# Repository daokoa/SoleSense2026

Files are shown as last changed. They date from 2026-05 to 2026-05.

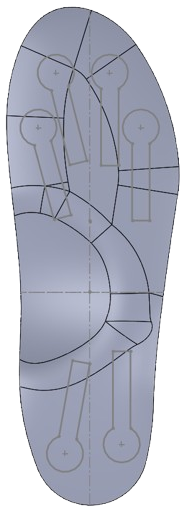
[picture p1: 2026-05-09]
software/frontend/solesense-v2/solesense.png

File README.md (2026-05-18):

# SoleSense







A 3D-printed smart running insole that runs a full gait analysis offline -- cadence, ground contact time, impact rate, pronation, foot-pressure heatmap, and research-backed injury flags -- and serves it over the device's own WiFi access point. No app, no cloud, no internet.

*UCI · Spring 2026*

---

## Quickstart

1. **Power on** the insole.
2. **Connect** your phone to WiFi `SoleSense` (password `solesense`).
3. **Open** `http://192.168.4.1/` (or `http://solesense.local/` on iOS / macOS).
4. **Sign in**, tap **Start Run**, run, tap **Stop**, read the report.

---

## Features

**Firmware** -- ESP32-C3 at 500 Hz
- Six-FSR matrix scan plus MPU-6050 IMU. All analysis runs on-device.
- Incremental Goertzel FFT, top-N outlier buffer, Welford running stats -- no raw samples are stored.
- Multi-slot crash-recoverable run snapshots in flash; runs survive WiFi blips and phone disconnects.
- NVS-backed user accounts with SHA-256 + per-user salt PIN hashing. One in-RAM session at a time.

**Frontend** -- single self-contained HTML file
- Sign-in and device-claim flow, live timer, anatomical foot diagram with real-time FSR fill.
- Report screen with verdict card, foot-pressure heatmap, findings cards, and an optional AI Coach. The Coach is proxied through a Cloudflare Worker that holds the OpenAI key -- the device never touches it.

**Injury flags** -- research-backed thresholds (full citations in [`docs/research.md`](docs/research.md))
- Heel striking · high impact rate · low cadence · overpronation · supination · medial/lateral asymmetry · FSR saturation diagnostic

---

## How it works

The MCU samples 6 FSRs and 6 IMU axes at 500 Hz and runs the full analysis on-device. FFT magnitudes, Welford stats, and the outlier buffer flush every 3 s to a 10-slot ring buffer in flash. The phone is a thin renderer: it polls `/api/run-state` for the timer and `/api/run-report` for the metrics. Disconnects pause the run cleanly; reconnects resume from the latest valid flash slot.

Full architecture rationale: [`docs/design/specs/2026-05-06-v0.2-data-architecture.md`](docs/design/specs/2026-05-06-v0.2-data-architecture.md).

---

## Hardware

| Component | Role | Status |
|---|---|---|
| Seeed XIAO ESP32-C3 | MCU, WiFi AP, HTTP server | flashed, running |
| MPU-6050 | 6-axis accel + gyro (I²C @ `0x68`) | wired, reads validated |
| FSR 402 × 6 | Pressure sensors (3-zone × medial/lateral) | wiring in progress |
| 1N5819 Schottky × 6 | One per FSR -- prevent voltage leakage between sensors during matrix scan | wired in WD4 |
| LIR2450 × 3 (parallel) | 3.7 V Li-ion coin cells, ~360 mAh | pending |
| TPU 85A | 3D-printed insole shell | pending |

---

## Pin map

Per [`hardware/electricalpins.pdf`](hardware/electricalpins.pdf); pin constants in [`firmware/SoleSenseV2/config.h`](firmware/SoleSenseV2/config.h).

| XIAO pin | GPIO | Use |
|---|---|---|
| D0 / A0 | 2 | ADC A — shared by FSR 1A & 2A |
| D1 / A1 | 3 | ADC B — shared by FSR 1B & 2B |
| D2 / A2 | 4 | ADC C — shared by FSR 1C & 2C |
| D4 | 6 | I²C SDA → MPU-6050 |
| D5 | 7 | I²C SCL → MPU-6050 |
| D6 | 21 | MPU-6050 INT (reserved) |
| D7 | 20 | FSR Set 1 power (FSRs 1A, 1B, 1C) |
| D8 | 8 | FSR Set 2 power (FSRs 2A, 2B, 2C) |
| D9 | 9 | Wake button (on-board BOOT) |

### FSR wiring

**Three pull-down resistors total**, one per ADC pin -- *not* one per FSR. Each pull-down forms the bottom half of a voltage divider with whichever of the two FSRs on that ADC is currently powered.

```
D7 ──[FSR 1A]──┐
                ├── D0 ──[10 kΩ]── GND
D8 ──[FSR 2A]──┘
```

The firmware time-multiplexes which set is active. Only one FSR is ever in the divider at a time; the inactive set's power pin is driven LOW, so any ghost-current path through the unpowered FSR shorts to ground rather than perturbing the active read.

### FSR → zone mapping (Choi 2024, +E-at-heel)

| Channel | FSR | Zone |
|---|---|---|
| ch0 | 1A | Heel medial |
| ch1 | 1B | Heel lateral |
| ch2 | 1C | Midfoot medial |
| ch3 | 2A | Midfoot lateral |
| ch4 | 2B | Forefoot medial |
| ch5 | 2C | Forefoot lateral |

---

## API

| Method | Path | Auth | Purpose |
|---|---|---|---|
| `GET`  | `/` | public  | Serves the SPA from LittleFS |
| `GET`  | `/api/device` | public  | Firmware version, board, sample rate, free heap, fs bytes |
| `GET`  | `/api/sensor` | public  | Live FSR + IMU snapshot (`fsr[]`, `fsrEma[]`, `ax/ay/az`, `gx/gy/gz`) |
| `GET`  | `/api/run-state` | public  | `recording, run_active, elapsed_ms, sample_count, clients_connected, outlier_count` |
| `GET`  | `/api/run-report` | public  | Final metrics: steps, cadence, contactMs, loadingRate, pronate, medialPct, lateralPct, zoneAvg, imuConnected, imuImpacts, flags |
| `GET`  | `/api/run-spectrum` | public  | FFT magnitude (12 channels × 18 bins, Goertzel) |
| `GET`  | `/api/run-outliers` | public  | Top-N outliers (`ts, channel, value, sigma`) |
| `GET`  | `/api/storage-state` | public  | Slot count + per-slot byte usage |
| `POST` | `/api/storage-selftest`  | public  | On-bench validation of the ring buffer |
| `POST` | `/api/fft-selftest` | public  | 1.95 Hz sine validation -- expect ~100 mag on the on-bin frequency |
| `GET`  | `/api/auth/state` | public  | `ownerExists, sessionActive, username, userCount, maxUsers` |
| `POST` | `/api/auth/register` | public, capped (`MAX_USERS=50`, 3-per-60-s) | Walk-up signup; first call claims the device |
| `POST` | `/api/auth/login` | rate-limited | `username, pin → token, body_kg` |
| `POST` | `/api/auth/logout` | session | Clear active session |
| `GET`  | `/api/auth/profile` | session | Current user info |
| `POST` | `/api/auth/profile` | session | Update body_kg / height_cm for the current user |
| `POST` | `/api/start` | session | Begin recording |
| `POST` | `/api/stop` | session | End recording, flush state |
| `POST` | `/api/data/clear` | session | Wipe all `/run_slot_*.bin` files (resets Last Report) |
| `POST` | `/api/calibrate/zero` | session | Zero the 6 FSRs (insole unloaded) |
| `POST` | `/api/calibrate/imu` | session | Zero accel + gyro (insole flat) |
| `POST` | `/api/sleep` | session | Enter deep sleep; wake on GPIO9 LOW |

Protected endpoints require `Authorization: Bearer <token>`. Handler-by-handler detail in [`firmware/SoleSenseV2/README.md`](firmware/SoleSenseV2/README.md).

---

## Setup & build

### One-time Arduino IDE setup

**Arduino IDE 2.3.8+** -- Tools menu:
- Board: `XIAO_ESP32C3`
- Partition Scheme: `Default 4MB with spiffs (1.2MB APP / 1.5MB SPIFFS)`
- USB CDC On Boot: `Enabled`

**Libraries** (Library Manager): `ESPAsyncWebServer` and `AsyncTCP`, both by **ESP32Async**. (`WiFi`, `LittleFS`, `Preferences`, `Wire` ship with the ESP32 core.)

### Flash from terminal

```bash
ARDUINO_CLI="/Applications/Arduino IDE.app/Contents/Resources/app/lib/backend/resources/arduino-cli"

# Firmware
"$ARDUINO_CLI" compile --fqbn esp32:esp32:XIAO_ESP32C3 firmware/SoleSenseV2
"$ARDUINO_CLI" upload  --fqbn esp32:esp32:XIAO_ESP32C3 --port /dev/cu.usbmodem2101 firmware/SoleSenseV2

# Frontend (LittleFS partition)
cp software/frontend/solesense-v2/index.html firmware/SoleSenseV2/data/index.html
bash firmware/SoleSenseV2/flash-littlefs.sh
```

Close any open Serial Monitor before flashing -- Arduino IDE auto-spawns a `serial-mo` process that holds the port.

### Expected boot output

```
=== SoleSense v0.2 booting ===
[FS] Mounted - <N> / 1441792 bytes used
[Sensors] FSR sets + MPU-6050 initialised
[Storage] init: <N>/10 slot files present
[Auth] init; ownerExists=<yes|no>
[WiFi] AP 'SoleSense' up at 192.168.4.1
[mDNS] solesense.local resolving
[HTTP] server started
[Timer] 500 Hz sampling armed
```

---

## Repository layout

```
solesense/
├── README.md                         · this file
├── LICENSE                           · MIT
│
├── firmware/
│   ├── README.md
│   ├── SoleSenseV2/                  · canonical firmware (Arduino)
│   │   ├── SoleSenseV2.ino
│   │   ├── config.h, state.*, sensors.*, fft.*, outliers.*, stats.*, storage.*, auth.*, http_routes.*
│   │   ├── flash-littlefs.sh
│   │   └── data/index.html           · LittleFS copy of the SPA
│   └── imu-test/                     · standalone MPU-6050 smoke-test sketch
│
├── software/
│   ├── README.md
│   ├── frontend/
│   │   ├── README.md
│   │   ├── mock-server.py            · Python http.server simulating the firmware
│   │   └── solesense-v2/index.html   · canonical SPA
│   ├── backend/
│   │   └── analyze-worker/           · Cloudflare Worker (holds the OpenAI key)
│   └── scripts/                      · host-side Python tooling (FSR + IMU bring-up)
│
├── hardware/
│   ├── cad/                          · SolidWorks parts + assemblies
│   ├── electrical/Solesense_WD.*     · KiCad schematic + PCB
│   ├── 3d printing/                  · sliced .3mf gcode (housing + lid)
│   └── electricalpins.pdf            · canonical pin assignment reference
│
└── docs/
    ├── research.md                   · peer-reviewed sources
    └── design/
        ├── specs/                    · architecture + profile-system specs
        └── plans/                    · firmware implementation plan
```

---

## Roadmap

### Shipped
- All run state lives on the MCU. The run timer is derived from the latest valid flash slot, so disconnects pause cleanly and reconnects resume from persisted state.
- 500 Hz sampling with incremental Goertzel FFT; RAM usage is rate-independent.
- Time-domain step counter and ground contact time (any-zone OR-gate, 250 ms refractory, IMU sensor fusion when wired).
- FSR-jerk loading rate (BW/s), converted using the logged-in user's body weight.
- Three-zone medial/lateral sensor layout (Choi 2024, +E-at-heel).
- Anatomical foot diagram with live FSR fill on the recording screen, plus a pressure heatmap on the report.
- NVS-backed user accounts (PIN auth and walk-up self-signup), mDNS hostname, captive-portal-free flow.
- AI Coach via Cloudflare Worker, which keeps the OpenAI key off the device.

### Open follow-ups
- Per-FSR saturation calibration. The loading-rate conversion currently assumes `ADC = 4095 ↔ 10 kg of force` uniformly across channels.
- EMA-baseline tracking in the step detector to absorb FSR drift from sweat and temperature.
- 30-second real-run validation on a fully wired insole.
- Pick a canonical firmware build system (Arduino IDE vs PlatformIO).
- Inline Google Fonts as base64 so the AI Coach offline fallback survives even when the UI uses webfonts.

---

## Team

| Name | Role |
|---|---|
| Norton Hoang | Electrical & Firmware Lead |
| Maxim Varakuta | Electrical & Firmware |
| Jordan Chan | Mechanical Lead |
| Kiara Peters | Mechanical |
| James Kim | Mechanical |
| Daniel Grivennikov | Mechanical |
| Ethan Kim | Mechanical |
| Andony Velasquez | Software Lead |
| Dao Doan | Firmware / Software |
| Jasmine Dhaliwal | Software |
| Natalie Dai | Software |

---

## Documentation

- [`firmware/README.md`](firmware/README.md) -- firmware overview and flash instructions
- [`firmware/SoleSenseV2/README.md`](firmware/SoleSenseV2/README.md) -- module status, security model, caveats
- [`software/README.md`](software/README.md) · [`software/frontend/README.md`](software/frontend/README.md) -- frontend and mock server
- [`software/backend/analyze-worker/README.md`](software/backend/analyze-worker/README.md) -- Cloudflare Worker (AI Coach)
- [`docs/research.md`](docs/research.md) -- peer-reviewed sources backing the thresholds and sample rate
- [`docs/design/specs/2026-05-06-v0.2-data-architecture.md`](docs/design/specs/2026-05-06-v0.2-data-architecture.md) -- data architecture
- [`docs/design/specs/2026-05-09-profile-system.md`](docs/design/specs/2026-05-09-profile-system.md) -- auth and profile system

---

## License

MIT -- see [`LICENSE`](LICENSE).

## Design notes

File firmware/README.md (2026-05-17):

# SoleSense Firmware

Canonical firmware lives in [`SoleSenseV2/`](SoleSenseV2/) (Arduino IDE, targets the **Seeed XIAO ESP32-C3**). 500 Hz sampling, modular `.h/.cpp` layout, on-MCU step detector with GCT and FSR-jerk loading rate, incremental Goertzel FFT (1024-sample window), top-N outlier buffer, multi-slot crash-recoverable flash storage, pause-on-disconnect, NVS-backed user accounts, and a captive-portal-free mDNS hostname. Sensor layout is 3-zone x medial/lateral (Choi 2024, +E-at-heel).

A diagnostic IMU smoke-test sketch lives in [`imu-test/`](imu-test/) for hardware bring-up; pair it with `software/scripts/watch-imu.py` for a live terminal dashboard.

## Design overview

`SoleSenseV2/` keeps every byte of run state on the MCU. It stores FFT magnitudes, outliers, and Welford stats in a CRC-protected ring buffer -- never raw samples -- and runs the full analysis on-device, so the browser is just a renderer. 500 Hz sampling gives enough resolution to capture impact rising edges for FSR-jerk extrapolation of loading rate. See [`docs/design/specs/2026-05-06-v0.2-data-architecture.md`](../docs/design/specs/2026-05-06-v0.2-data-architecture.md) for the architecture rationale.

## Sensor layout

Six FSRs, three zones, two sensors per zone:

| Channel | Position |
|---|---|
| ch0 | Heel medial |
| ch1 | Heel lateral |
| ch2 | Midfoot medial |
| ch3 | Midfoot lateral |
| ch4 | Forefoot medial (under 1st MT) |
| ch5 | Forefoot lateral (under 5th MT) |

## What's flashed on the board right now

```bash
curl --noproxy '*' -s http://192.168.4.1/api/device | python3 -m json.tool | head -3
```

`firmware` should read `SoleSense v0.2-dev` and `sampleRateHz: 500`. (`v0.2-dev` is the in-tree firmware string defined by `SS_FIRMWARE_VERSION` in `SoleSenseV2/config.h`; bump that string when cutting a release.)

## How to flash

```bash
ARDUINO_CLI="/Applications/Arduino IDE.app/Contents/Resources/app/lib/backend/resources/arduino-cli"
"$ARDUINO_CLI" compile --fqbn "esp32:esp32:XIAO_ESP32C3" firmware/SoleSenseV2
"$ARDUINO_CLI" upload  --fqbn "esp32:esp32:XIAO_ESP32C3" --port /dev/cu.usbmodem2101 firmware/SoleSenseV2
bash firmware/SoleSenseV2/flash-littlefs.sh
```

LittleFS data: `firmware/SoleSenseV2/data/index.html` should be a copy of `software/frontend/solesense-v2/index.html`.

> **Heads-up:** Arduino IDE auto-respawns its Serial Monitor whenever the XIAO re-enumerates after a flash. That holds the port and breaks the next upload. Close the Serial Monitor pane before flashing, or run `kill $(lsof -t /dev/cu.usbmodem*)` between attempts.

## Hardware setup

Pin map and matrix-scan FSR layout are documented in the [root README](../README.md). Key constants live in `firmware/SoleSenseV2/config.h`.

## Known caveats

1. **Loading rate** assumes a 70 kg body weight only when no user is logged in. Once a user signs in, their `body_kg` from the profile is used instead. The other calibration assumption (FSR full-scale ADC = 10 kg of force) is still hardcoded; per-FSR saturation calibration is future work.
2. **Step detector** uses fixed ADC thresholds gated by a 2-state Kalman filter (`R=25`, `Q` tuned for impact transients). FSR baseline drift from sweat and temperature is handled by the velocity-based toe-off, not by absolute thresholds.
3. **End-to-end hardware verification** -- bench-tested in pieces. A 30-second real-run test on a fully wired insole is the open follow-up.
4. **Step-detector debug `Serial.printf`** is still in the build (handy for bring-up). Strip it before a clean release.

## Cross-references

- Architecture spec: [`../docs/design/specs/2026-05-06-v0.2-data-architecture.md`](../docs/design/specs/2026-05-06-v0.2-data-architecture.md)
- Profile / auth spec: [`../docs/design/specs/2026-05-09-profile-system.md`](../docs/design/specs/2026-05-09-profile-system.md)

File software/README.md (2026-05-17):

# Software

Web-side and host-side code for SoleSense. The MCU firmware lives in [`../firmware/`](../firmware/); this folder holds everything that runs in the user's browser or on a host computer connected over USB or WiFi.

## Contents

| Folder | Purpose |
|---|---|
| [`frontend/`](frontend/) | The single-page web app served from the XIAO ESP32-C3 over its WiFi access point. One canonical SPA at `solesense-v2/` (auth and AI Coach). See [`frontend/README.md`](frontend/README.md). |
| [`backend/`](backend/) | Server-side helpers that need real internet. Hosts the Cloudflare Worker proxy that runs LLM-powered run analysis; the OpenAI key lives only there, as an encrypted secret. |
| [`scripts/`](scripts/) | Host-side Python utilities for FSR bring-up and debugging. Run from a laptop while the device serves its AP. |

## scripts/

Quick references. All run against `http://192.168.4.1` while connected to the SoleSense AP:

| Script | What it does |
|---|---|
| `identify-fsr.py` | Walks each FSR channel and prompts you to press a sensor, labelling which physical FSR maps to which `(set, ADC)` matrix index. Use during initial wiring. |
| `watch-fsr.py` | Streams live FSR readings to the terminal at ~5 Hz. Useful for sanity-checking that all 6 channels move when pressed. |
| `diag-fsr.py` | Cycles power sets and ADC pins independently to diagnose stuck-low, stuck-high, or floating pins. The first thing to run when channels look wrong. |

Run with:
```bash
python3 software/scripts/diag-fsr.py
```

## Future additions

When the team adds host-side analysis tooling, training pipelines for a CNN/LSTM model, or a mobile app wrapper, those go here too -- likely as `software/analysis/`, `software/training/`, or `software/mobile/`.

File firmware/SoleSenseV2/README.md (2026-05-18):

# SoleSense Firmware

All run state lives on the MCU. No browser-side analysis, and flash storage is crash-recoverable. Samples at **500 Hz** with a **3-zone medial/lateral sensor layout** (Choi 2024, with FSR E moved next to the heel).

## Background

- **Architecture spec:** [`../../docs/design/specs/2026-05-06-v0.2-data-architecture.md`](../../docs/design/specs/2026-05-06-v0.2-data-architecture.md)
- **Frontend (v0.2-aware viewer):** [`../../software/frontend/solesense-v2/index.html`](../../software/frontend/solesense-v2/index.html)

## Sensor layout

Six FSRs, three zones, two sensors per zone (one medial, one lateral). Drawn from Choi et al. 2024 ("Calibrating Low-Cost Smart Insole Sensors with Recurrent Neural Networks for Accurate Prediction of Center of Pressure", *Sensors* 24(15):4765), with FSR E relocated next to F so both sit at the heel.

| Channel | Position | Notes |
|---|---|---|
| ch0 | Heel medial | Inside-back of heel pad |
| ch1 | Heel lateral | Outside-back of heel pad |
| ch2 | Midfoot medial | Inside-middle, under the arch |
| ch3 | Midfoot lateral | Outside-middle |
| ch4 | Forefoot medial | Under 1st MT (just below hallux base) |
| ch5 | Forefoot lateral | Under 5th MT, near pinky toe |

The matrix-scan wiring (2 power sets x 3 ADC pins, with six 1N5819 Schottky diodes -- one per FSR -- preventing voltage leakage between sensors that share an ADC line) is unchanged; only the physical FSR positions differ. See [`../README.md#pin-map`](../README.md) for the wiring detail.

## Module status

| Module | File(s) | Status |
|---|---|---|
| Identity / constants | `config.h` | [x] done, sample rate 500 Hz |
| Run state machine + pause-on-disconnect | `state.h` / `state.cpp` | [x] done |
| Sensor reads (matrix-scan FSR + I^2C IMU) | `sensors.h` / `sensors.cpp` | [x] done |
| Outlier min-heap (top-N by sigma) | `outliers.h` / `outliers.cpp` | [x] done |
| Per-channel Welford stats | `stats.h` / `stats.cpp` | [x] done |
| 500 Hz hardware-timer sample loop | `SoleSenseV2.ino` | [x] done |
| Goertzel FFT, 1024-sample window, 0.49 Hz bin width | `fft.h` / `fft.cpp` | [x] done |
| Multi-slot ring-buffer flash storage | `storage.h` / `storage.cpp` | [x] done |
| Time-domain step detector (any-zone OR-gate, 250 ms refractory, peak-relative release) | `state.cpp` | [x] done |
| FSR + IMU sensor fusion (strike requires recent IMU impact when IMU is connected; falls back to FSR-only when not) | `state.cpp` + `SoleSenseV2.ino` | [x] done |
| Ground-contact-time | `state.cpp` | [x] done; heel-strike -> toe-off interval, [50, 800] ms valid range |
| Total-pressure aggregate (peak `SUM(ch0..5)`) | `SoleSenseV2.ino` | [x] done; exposed via `/api/run-report.maxTotalPressure` for diagnostics |
| HTTP routes (full set) | `http_routes.cpp` | [x] done |
| FSR-jerk loading rate (BW/s); uses logged-in user's body weight | `http_routes.cpp` + `SoleSenseV2.ino` | [x] done |
| Cadence sanity clamp (20-300 spm) | `http_routes.cpp` | [x] done |
| FSR-saturation injury flag | `http_routes.cpp` | [x] done |
| **Auth / profile system** | `auth.h` / `auth.cpp` | [x] done; NVS-backed users, SHA-256 + salt, owner-claim model, 30-min idle session, 3-failures -> 30-s lockout |
| Deep sleep + GPIO9 wake | `SoleSenseV2.ino` | [x] done (older esp-idf API for portability) |

## What works on hardware

If you flash v0.2 onto a wired XIAO:

- AP comes up (`SoleSense` / `solesense`) and every route responds.
- Recording state machine starts and stops, and pauses when the AP loses all clients.
- 500 Hz sampling routes each sample through outlier detection -> FFT -> step detector.
- Step count increments on each heel strike. Cadence = steps x 60 / runtime.
- Ground contact time averages valid heel-strike-to-toe-off intervals.
- Loading rate reports BW/s from peak heel d(ADC)/dt, scaled by the logged-in user's body weight (or a 70 kg fallback when no session is active).
- FFT magnitudes populate per channel and bin (validated against a Python reference, 0% on-bin error).
- Storage flushes a CRC-protected snapshot every 3 s into a 10-slot ring. Corrupted slots are rejected on load.
- `/api/run-state` reports live elapsed time, sourced from the latest valid flash slot rather than wall clock, so it pauses honestly during a disconnect.
- `/api/run-report` returns step count, cadence, contactMs, loadingRate (BW/s), pronation, zone breakdown (heel / midfoot / forefoot), the medial/lateral split, and the injury-flag set.
- `/api/storage-selftest` and `/api/fft-selftest` provide on-bench validation.

## Known caveats

These are *real numbers reported with explicit assumptions* -- not stubs.

1. **Body weight is per-user via the profile system.** Once an account is created with a `body_kg` value, the loading-rate BW/s conversion uses that value. If no session is active (e.g., a non-protected `/api/run-report` call), the calc falls back to a 70 kg assumption.
2. **Loading-rate FSR saturation assumption.** The conversion assumes the FSR plus voltage divider hits ADC=4095 at exactly 10 kg of force. The actual saturation point depends on the divider resistor. The `fsr_saturated` flag in the run report fires if peak total pressure suggests several channels hit the rail, telling the user "loading rate may be underreported." Per-divider calibration is the next refinement.
3. **IMU graceful fallback.** When the MPU-6050 is not soldered, `gImuConnected` stays `false` (zero stddev on accel_z) and the step detector skips IMU validation, so steps still count off the FSRs alone. Once the IMU is wired, the validation auto-engages.
4. **Step detector debug logs are still on.** `step_detector_update()` in `state.cpp` prints `[Step] tentative` and `[Step] STEP/discard` to Serial whenever it fires. Useful for bring-up; strip for clean release builds.
5. **Hardware verification gap.** The full "30-second run with rhythmic foot strikes" end-to-end test has not been recorded yet.

## Compile / flash

Sketch upload via the bundled arduino-cli:

```bash
ARDUINO_CLI="/Applications/Arduino IDE.app/Contents/Resources/app/lib/backend/resources/arduino-cli"
"$ARDUINO_CLI" compile --fqbn "esp32:esp32:XIAO_ESP32C3" firmware/SoleSenseV2
"$ARDUINO_CLI" upload  --fqbn "esp32:esp32:XIAO_ESP32C3" --port /dev/cu.usbmodem2101 firmware/SoleSenseV2
```

Or open `SoleSenseV2.ino` in Arduino IDE and click Upload -- the IDE picks up every `.h` and `.cpp` file in the same folder automatically. **Close the Serial Monitor before uploading or the port will be busy.**

LittleFS data (the v0.2-aware frontend):

```bash
cp software/frontend/solesense-v2/index.html firmware/SoleSenseV2/data/index.html
bash firmware/SoleSenseV2/flash-littlefs.sh
```

After flashing, verify:

```bash
curl --noproxy '*' -s http://192.168.4.1/api/device | python3 -m json.tool | head -3
```

`firmware` should read `SoleSense v0.2-dev` and `sampleRateHz` should read `500`.

## Security & resilience model

What's protected, what's not, and how the firmware survives the obvious failure modes.

### Data at rest

| Data | Where | Integrity | Confidentiality |
|---|---|---|---|
| User PINs | NVS namespace `solesense_auth` (`h_<user>` keys) | NVS provides per-page CRC and wear-leveling. Writes are atomic: a power loss mid-write either keeps the old value or rolls back, never half-applied. | SHA-256 with a 16-byte per-user random salt. Pulling the flash chip and dumping NVS reveals only `(salt, hash)` pairs. Recovering the PIN requires brute-forcing the hash, which on a 4-digit PIN is fast unless rate-limited at the auth layer (which it is, see below). |
| Run data | LittleFS `/run.bin`, 10-slot ring buffer | Each slot is wrapped with a magic header (`0x55EAB001`), CRC32, and magic trailer (`0xC0DEF00D`). On boot or reconnect we scan all 10 slots and pick the newest with a valid trailer. A power loss mid-flush corrupts at most one slot; the previous valid slot is loaded transparently. | Not encrypted. Anyone with physical USB can read the recorded run. |
| Calibration offsets (FSR / IMU) | RAM only (zeroed on boot) | n/a | Re-run `/api/calibrate/zero` and `/api/calibrate/imu` after each reboot. Persisting to NVS is a v0.3 todo. |
| Body weight | NVS `solesense_auth` (`w_<user>`) | NVS-protected | Plaintext within NVS -- see the PIN row for what that means. |

### Auth attacks

| Attack | Defense |
|---|---|
| **PIN brute-force over the AP** | 3 wrong PINs in any 60-second window for the same username triggers a 30-second lockout (in-RAM, per-username; see `auth.cpp::auth_record_failure_and_check_lockout`). |
| **Session-token forgery** | 32-byte token from `esp_random()` (hardware TRNG), 256 bits of entropy. Compared with `memcmp` (constant-time enough -- the token is a one-shot, not an HMAC). |
| **Token replay after expiry** | Every successful auth check compares `expires_ms` against `millis()` and drops the session if past. Idle timeout: 30 minutes. |
| **Token replay after logout** | Logout clears the slot in RAM. Subsequent requests with that token get 401. |
| **Walk-up account creation** | Anyone on the SoleSense AP can register an account (the shared WiFi password is the access gate). Capped at `MAX_USERS = 50` and rate-limited to 3 registrations per 60 seconds per device. The first register call also "claims" the device by writing `owner_user` to NVS. |
| **Physical USB attacker** | Out of scope. They can re-flash firmware, and nothing in software stops that. The `factory_reset` USB-serial command is intentionally available so a legitimate device owner can recover from a forgotten PIN. |
| **DoS via login flood** | Per-username lockout limits the cost. There is no global rate limiter today; if the device is exposed to a hostile network for long periods, add one in `auth.cpp`. |

### Run-time edge cases

| Edge case | Behaviour |
|---|---|
| **WiFi client disconnects mid-run** | `state.cpp` flips `gRunActive=false`, freezes the elapsed-time counter, and keeps the last sample-loop state in RAM. On reconnect, the counter resumes. The frontend's `pollRunState` shows a "Paused" badge while disconnected. |
| **Phone leaves AP entirely (out of range)** | Same as above on the device side. The frontend's `/api/run-state` polls fail; after 3 consecutive failures the recording screen shows a `Device unreachable -- reconnect to SoleSense WiFi` banner instead of fabricating timer values. |
| **Power loss mid-recording** | The last valid CRC-protected slot in `/run.bin` is the source of truth on next boot. At most ~3 seconds of post-flush data is lost (the inter-flush interval). |
| **User hits Stop with bad WiFi** | The frontend retries `/api/stop` 4 times with backoff (`authPostRetry`). 409 ("not recording") is treated as success. After failures, the local UI advances to the report anyway, and `/api/run-report` will succeed once the device is reachable again. |
| **AI Coach with no internet** | The frontend's `runAiAnalysis()` catches the fetch failure and renders a friendly message ("Couldn't reach the AI coach...") under the Coach panel. The rule-based flags above remain authoritative. |
| **AI Coach with internet but worker quota hit** | The Worker returns 502 with a structured error, and the frontend surfaces the message in the same error banner. |
| **`/api/start` while already recording** | 409. The frontend doesn't depend on this for correctness. |
| **`/api/stop` while idle** | 409. Treated as success by `authPostRetry`. |
| **Sleep request while recording** | 409 -- `gSleepRequested` is only honoured from idle. |
| **NVS write failure during register** | `auth_register` returns -2 with a `[Auth] register NVS write failed: w1=... w2=... w3=...` log line. The frontend shows "nvs error". The user retries (transient) or runs `factory_reset` over USB serial. |
| **Concurrent registers** | The MCU is single-core and AsyncTCP serializes route handlers, so only one register runs at a time. |
| **Browser cache after LittleFS reflash** | A documented gotcha. A hard refresh is required. The firmware version and sample rate in `/api/device` are the easiest way to confirm what's actually running. |

### Frontend-only resilience

- `localStorage` corruption -> next protected fetch returns 401 -> `authFetch` wipes localStorage and bounces to login.
- The token is never logged or written to a query string.
- The Cloudflare Worker URL is the only outbound network call. If it's blocked (corporate WiFi, captive portal), the AI Coach panel falls back to its error state without breaking the rest of the report.

### Out of scope

- **Encrypted run data at rest.** Adding AES-CTR with a key derived from the owner's PIN would protect against flash-chip extraction, but it bricks the device on PIN loss. Not worth it for our use case.
- **Per-device certificates / TLS on the AP.** SoleSense serves plaintext HTTP over its own AP, so anyone on the AP can sniff the JSON. The defense: it's the user's own AP, the WiFi is password-gated (`solesense`), and there's no PII richer than body weight on the wire.
- **Audit log of state transitions.** Recording start/stop happen, but there's no per-user history of past runs persisted across reboots. Once the IMU lands and the run-history feature ships, this becomes worth doing.

## Auth / profile system

Spec: [`../../docs/design/specs/2026-05-09-profile-system.md`](../../docs/design/specs/2026-05-09-profile-system.md).

- Storage: NVS namespace `solesense_auth`, per-user keys `s_<user>` (16-byte salt), `h_<user>` (32-byte SHA-256 hash), `w_<user>` (float body_kg), plus globals `owner_user` (string) and `uc` (uint16 user count).
- Hashing: SHA-256(pin || 16-byte random salt) via mbedtls.
- One active session at a time, RAM-only, 30-minute idle timeout.
- **Self-signup.** Any client on the SoleSense AP can create an account. The first registration becomes the "owner" (a label, not a role); subsequent accounts are equal peers.
- **Atomic registration.** Writes salt -> hash -> body_kg in sequence, rolling back partial state on any NVS failure. A username slot is never left half-written.
- **Anti-abuse caps:**
  - **`MAX_USERS = 50`** total accounts. Further registrations return HTTP `507 Insufficient Storage` with the message *"This device is full (account limit reached)."*
  - **Registration rate limit** = `REG_RATE_MAX_PER_WINDOW (3) / REG_RATE_WINDOW_MS (60 s)` global sliding window. A 4th signup within 60 s returns HTTP `429`.
- Login PIN rate limiter: 3 failed PINs in 60 s -> 30 s lockout for that username.

Endpoints:

| Method | Path | Auth | Notes |
|---|---|---|---|
| `GET`  | `/api/auth/state` | public  | `{ ownerExists, sessionActive, username, userCount, maxUsers }` |
| `POST` | `/api/auth/register`  | public, capped (`MAX_USERS=50`, 3-per-60s) | URL-encoded `username, pin, body_kg, height_cm`. First call also claims the device (`owner_user` written to NVS). |
| `POST` | `/api/auth/login` | public  | URL-encoded `username, pin` -> `{ ok, token, body_kg }` |
| `POST` | `/api/auth/logout` | session | clear current session |
| `GET`  | `/api/auth/profile` | session | current user info |

Protected endpoints (require `Authorization: Bearer <token>`):
`POST /api/start`, `POST /api/stop`, `POST /api/sleep`, `POST /api/calibrate/zero`, `POST /api/calibrate/imu`.

Public read-only endpoints (still available without a token, used for AP discovery and live diagnostics): `GET /api/device`, `GET /api/sensor`, `GET /api/run-state`, `GET /api/run-report`, `GET /api/run-spectrum`, `GET /api/run-outliers`, `GET /api/storage-state`.

To factory-reset the auth NVS, run `Preferences.clear()` over USB serial. There is no in-app reset path.

## Tasks for new contributors

In priority order:

1. **Per-FSR saturation calibration.** Apply a known weight (5 kg) and capture each channel's ADC reading. Use that to fit a per-channel `force_per_count` so loading rate isn't bottlenecked by the 4095=10 kg assumption.
2. **Hardware verification.** A 30 s real-run test on a wired insole. Confirm cadence, pressure distribution, contact time, loading rate, and IMU validation all behave under real running.
3. **EMA-baseline step detector.** The fixed-threshold Schmitt trigger can drift with FSR baseline (sweat, temperature). The `heelMean` and `heelStddev` args are already plumbed; wire them into a slow EMA baseline.
4. **Strip Serial debug** once confidence is high.
5. **Auto-stop after silence.** If no FSR strike for >120 s during a recording, auto-invoke `/api/stop` to catch "user forgot to stop". Currently a TODO.

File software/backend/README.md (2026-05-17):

# Backend

Server-side helpers that complement the offline-first SoleSense device. The XIAO ESP32-C3 hosts its own WiFi AP and never reaches the internet, so anything that needs an external API (LLM analysis, future cloud sync) lives here instead.

## Contents

| Folder | Purpose |
|---|---|
| [`analyze-worker/`](analyze-worker/) | Cloudflare Worker that proxies LLM-powered run analysis. Holds the OpenAI API key as an encrypted secret. The frontend POSTs a run report and user profile, and gets back personalized injury-risk markdown. |

## Adding new services

Each service should:

- Read its API keys exclusively from environment variables or secret-manager bindings. **Never** check secrets into git.
- Be deployable independently (no shared build pipeline).
- Document `local dev` and `deploy` commands in its own README.
- Follow the same JSON contract shape: `{ ok: boolean, ... }` for success, `{ ok: false, error: string }` for failure.

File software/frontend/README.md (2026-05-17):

# SoleSense Frontend

Single-page web app served from the XIAO ESP32-C3 over its WiFi AP. One canonical SPA, no internet dependency.

```
software/frontend/
|-- README.md
|-- mock-server.py        <- Python http.server that simulates the firmware
`-- solesense-v2/
    `-- index.html        <- the SPA (auth, recording, report, AI Coach)
```

The SPA is a single self-contained file using system fonts: no build step, no external resources. The recording screen shows a 3-zone medial/lateral foot diagram (the actual insole CAD render, cut out with a transparent background) with live FSR fill on the six visible sensor pads.

## Verify what's flashed

```bash
curl --noproxy '*' -s http://192.168.4.1/api/device | python3 -m json.tool | head -3
```

`firmware` should read `SoleSense v0.2-dev` and `sampleRateHz: 500`. The LittleFS `index.html` is a copy of `solesense-v2/index.html` made at flash time.

## Switch the UI on the device

If you've changed `solesense-v2/index.html` and want the new version on the board:

```bash
cp software/frontend/solesense-v2/index.html firmware/SoleSenseV2/data/index.html
bash firmware/SoleSenseV2/flash-littlefs.sh
```

The flash script auto-detects mklittlefs, esptool, and the USB port. Close any open Serial Monitor first -- it locks the USB port and the upload fails with `exit status 2`.

## Preview locally without flashing

`mock-server.py` simulates the firmware backend with synthetic stride-shaped sensor data:

```bash
python3 software/frontend/mock-server.py
```

Open <http://localhost:8080/>. The mock implements a subset of the HTTP API: live `/api/sensor` polls, `/api/start`, `/api/stop`, and `/api/calibrate/*`. The run-state, run-report, and `/api/auth/*` endpoints aren't mocked, so use real firmware to validate those.

## Auth flow

The SPA loads the auth screen first. It polls `/api/auth/state` to decide what to show:

- **No owner yet** -- claim mode. The user picks a username, PIN, and body weight, and becomes the device owner.
- **Owner exists** -- sign-in form, with a "Create one" toggle that flips to self-signup (subject to the firmware-side caps: max 20 accounts, 3 signups per 60 s).

The token is cached in `localStorage` under `solesense_token`. `body_kg` and `username` are cached alongside so Settings can render "Signed in as ..." without a round-trip.

An `authFetch()` helper attaches `Authorization: Bearer <token>` to every protected call. Any 401 wipes localStorage and bounces the user back to login.

To factory-reset the user database, send `factory_reset\n` over USB serial; details in [`../../firmware/SoleSenseV2/README.md`](../../firmware/SoleSenseV2/README.md).

## Pressure-distribution math

Zone bars on the report screen render percentages of total foot pressure during the run, not raw ADC counts. The bars sum to 100 %. The three zones (Heel, Midfoot, Forefoot) match the 3-zone medial/lateral sensor layout (two sensors per zone, averaged).

## Medial / Lateral, not Left / Right

The SPA labels the L/R-style split as **Medial / Lateral** because the system has one insole. We measure inside-of-foot vs outside-of-foot pressure on a single foot; left foot vs right foot needs a second insole. The injury flag is named `medial_lateral_asym`.

## Injury-flag thresholds (hardcoded)

Cadence < 160 spm, pronation > 15 deg/s, supination < -8 deg/s, asymmetry > 10 %, impact rate > 80 BW/s. All come from peer-reviewed gait research (sources in [`../../docs/research.md`](../../docs/research.md)). They are not user-tunable in the UI today; the firmware has a `/api/settings` endpoint and an NVS-backed thresholds struct for future tooling.

## Known limitations and gaps

- **Loading rate / Impact rate** reports a real BW/s value via FSR-jerk extrapolation, with the UI showing a Healthy / Elevated / High category. The conversion uses the logged-in user's body weight from their profile; the FSR saturation point is still hardcoded at full-scale ADC = 10 kg.
- **Browser cache pitfall.** When LittleFS gets a frontend update (new auth fields, renamed keys), iOS Safari and desktop browsers keep serving the cached old `index.html`, and you'll see undefined values render as `NaN` or `26500 %`. Force-refresh after every LittleFS reflash.
- **Mock server is incomplete.** It doesn't simulate `/api/run-state`, `/api/run-report`, or the auth endpoints, so those screens need real firmware to exercise.

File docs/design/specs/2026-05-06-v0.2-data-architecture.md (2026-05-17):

---
project: SoleSense
component: Data architecture
date: 2026-05-06
status: design-discussion snapshot from 2026-05-06; superseded by the as-built numbers in firmware/SoleSenseV2/README.md (500 Hz sampling, 18 bins x 12 channels = 216 FFT coefficients, 10-slot ring buffer). The high-level architecture below still describes the system; the specific quantities in the early sections are the original design proposal.
---

# Data Architecture -- MCU as Source of Truth

## The problem this design solves

A naive recording flow leaves data living in two unsafe places:

- **Browser-polling UI**: the phone polls `/api/sensor` at 5 Hz and accumulates samples in a JS array in browser memory. WiFi blip -> half-full array -> lost run.
- **CSV-streaming firmware**: raw CSV streams to LittleFS and is downloaded to the phone after `/api/stop` for client-side analysis. Slightly safer than the browser-polling path because the data lives on the MCU, but still fragile during the run -- the phone's timer drifts from the MCU's, and the analysis code lives in JS, which can't run if the page closes.

Either way, a momentary disconnection during a run cooks the data, and the phone holds state it shouldn't.

## Directive

**Nothing is stored on the device that streams the website (i.e. the phone/browser).** The MCU is the only place data lives. The phone is a viewer that asks the MCU what to render.

This means:

1. The phone-side `sensorData` array is gone.
2. The phone-side run timer is gone -- the MCU reports elapsed time.
3. The phone-built CSV download path is gone -- if a CSV export is needed, the MCU streams it.
4. On disconnect/reconnect, the phone re-queries the MCU and resumes from whatever state the device's state machine is in.

## Pipeline

```
Sensors @ 50-100 Hz
        |
        
   ,--------------------------------.
   | MCU RAM                         |
   |  |-- Live FFT coefficients (~3000 sine terms)        |
   |  |-- Top-N outlier buffer (capacity ~100)             |
   |  `-- Run metadata (start_ms, sample_count, ...)         |
   `--------------------------------'
        |  every ~3 seconds (benchmark; tune later)
        
   ,--------------------------------.
   | MCU LittleFS                    |
   |  Multi-slot ring buffer (~10 slots).   |
   |  Each slot = one snapshot of {coefs, outliers, meta, header, trailer}. |
   |  Newest-valid is found by header timestamp; trailer checksum proves the write completed. |
   `--------------------------------'
        |  on demand (`GET /api/run-state` etc)
        
   Phone (viewer only)
```

### 1. Sample into RAM (no raw 50 Hz stream is ever stored)

We keep sampling at 50-100 Hz internally (rate TBD; see "Decisions still open" below) but **never write the raw stream to flash**. Earlier math showed raw 50 Hz fills the 1.5 MB partition in ~5 minutes and raw 100 Hz fills it in ~2.5 minutes. Storing every sample is unaffordable, so we don't.

### 2. Decompose into a Fast Fourier Transform (FFT)

Any time-series signal can be expressed as a sum of sine waves. In practice you cap that sum -- say 3000 terms -- and pick a target error rate (e.g. <=1%). Each new sample updates those 3000 coefficients incrementally instead of being stored individually.

> *"3000 sign waves represent the entire run."*

What this buys us:

- **Bounded RAM**: storage cost is fixed (3000 x bytes-per-coefficient) regardless of run length. A 1-minute run and a 60-minute run use the same memory.
- **Bounded flash**: the same applies to the persisted snapshot.
- **Frequency-domain features come for free**: cadence, stride frequency, and dominant gait frequency are coefficients in the transform -- no separate detection step needed.

### 3. Outliers go in a separate list

Outliers (samples > N sigma from the local mean, or peak detections that exceed a threshold) are **excluded from the FFT** because they would skew the spectrum. They are also the most clinically interesting moments -- heel-strike spikes, asymmetric load events, sudden impacts.

So we maintain a **fixed-capacity top-N outlier buffer** (~100 entries) alongside the FFT coefficients. When the buffer fills, evict the smallest entry by magnitude.

> *"You don't count it. ... you have a separate space for top 100 outliers." — David the Benevolent King*

Each outlier entry: `{timestamp_ms, sensor_id, value, type}`.

### 4. Flash flush: multi-slot ring buffer with atomic-write semantics

Every ~3 seconds, copy the RAM state into a new flash slot.

**Why a ring buffer instead of overwrite-in-place:**

- A mid-write crash leaves the file half-written. If we always wrote to the same slot, a single crash would corrupt everything; a ring buffer keeps the previous slot intact.
- It spreads writes across slots for wear-leveling (LittleFS already does some of this; the ring buffer is belt-and-suspenders).

**Slot count**: ~10 slots, giving ~30 seconds of recoverable history. Tune later.

**Slot layout**:
```
,--------------------------------------.
| Header  : { slot_n, timestamp_ms,    |
|            schema_version, length }   |
|--------------------------------------+
| Body    : FFT coefficients +          |
|           outlier buffer +            |
|           run metadata                |
|--------------------------------------+
| Trailer : { crc32 over header+body,   |
|            magic_complete }           |
`--------------------------------------'
```

**On boot or reconnect:**
1. Scan all 10 slots.
2. Discard any slot whose trailer's `magic_complete` isn't set or whose CRC doesn't match (incomplete write).
3. From what's left, pick the slot with the highest header timestamp. That's the newest known-good save.

> *"How do you know if the file was finished saving? ... Compare it to the last ... At the top of the file, you have a writing thing."*

### 5. HTTP API (phone <-> MCU)

| Endpoint | Purpose |
|---|---|
| `POST /api/start` | Start a run. MCU resets RAM state, marks `recording=true`. |
| `POST /api/stop`  | End run. MCU does a final flash flush. |
| `GET /api/run-state` | Returns `{recording, run_active, elapsed_ms, sample_count, last_flush_age_ms, clients_connected}`. `elapsed_ms` is the value from the latest valid flash slot -- not a wall-clock since `/api/start`. `run_active` is true only when at least one client is on the AP and sampling is advancing. The phone polls this for the live timer. |
| `GET /api/run-spectrum` | Returns the current FFT coefficients (or a downsampled summary for display). |
| `GET /api/run-outliers` | Returns the current outlier buffer. |
| `GET /api/run-report` | Returns the analyzed metrics computed on-MCU from the FFT + outliers (cadence, GCT, pronation, L/R balance, injury flags, pressure distribution). |
| `GET /data.csv` | Optional. If CSV export is wanted, the MCU reconstitutes a sampled stream from the FFT and serves it. The phone never builds CSVs anymore. |

The phone NEVER caches any of this. Every navigation re-queries.

### 6. Reconnect flow

1. The phone loses WiFi briefly. JS state may be wiped, depending on whether the page reloads.
2. The phone reconnects to the SoleSense AP.
3. The page loads and calls `GET /api/run-state`.
4. If `recording=true`, the page resumes the live UI from the `elapsed_ms` the MCU reports.
5. If `recording=false` and a finished run exists in flash, the page goes to the report screen and pulls `/api/run-report`.

No data lost. The phone is a thin viewer.

### 7. Connection-aware time keeping (the duration timer rules)

Two firm rules from the team:

> **The duration timer pauses when the phone disconnects.**
> **Duration is derived from what's actually saved to flash, not from a wall-clock since `/api/start`.**

This rules out the naive `elapsed_ms = millis() - run_start_ms` approach. Instead:

**Source of truth for elapsed time** = `latest_valid_flash_slot.run_elapsed_ms`.

In other words, the MCU flushes a snapshot to flash every ~3 s. Each snapshot has a `run_elapsed_ms` field in its header. The `/api/run-state` endpoint returns the value from the most recent valid slot -- never a more-up-to-date in-RAM number that hasn't been persisted yet. So if the phone disconnects mid-flush, on reconnect it sees the duration as of the last successful flush, which matches the duration of the data that actually survives.

**Pause-on-disconnect mechanism** (firmware):

```
loop():
    clients = WiFi.softAPgetStationNum()
    if recording:
        if clients > 0:
            # phone (or some client) is connected
            run_active = true
            # sample, update FFT, increment outlier counts as usual
            if (millis() - last_flush_ms) >= FLUSH_INTERVAL_MS:
                run_elapsed_ms += (millis() - last_active_ms)
                last_active_ms = millis()
                flush_to_next_slot(run_elapsed_ms)
        else:
            # nobody watching -- pause
            run_active = false
            last_active_ms = millis()   # so the elapsed-ms calc skips this gap on resume
```

In plain English: the MCU only advances `run_elapsed_ms` while at least one client is connected to the AP. While the AP is empty, nothing is sampled into the FFT, no flushes happen, and the elapsed counter doesn't grow. When the phone comes back, sampling resumes and the next flush picks up where the previous one left off.

**Why client-count instead of a JS heartbeat:** it's simpler. The AP already knows when stations come and go via 802.11, so no extra ping endpoint is needed.

**Why pause sampling (not just pause the timer):** because the user told us "the only data saved are these transforms in flash." If we kept sampling during a disconnect and folded those samples into the FFT, we'd pollute the transform with noise from a period the user can't see and didn't authorize. Pausing both keeps the transform clean.

**Edge cases:**

- Phone disconnects exactly during a flush. The flush completes (it's a single `LittleFS` write that takes ms, not seconds), the slot's CRC trailer is written, and the slot is valid. Reconnect picks it up. No corruption.
- Phone never reconnects. After `/api/stop`, the MCU writes a final slot with `run_done=true`. The data sits in flash until either `/api/data/clear` or the next `/api/start`.
- Multiple clients connect (e.g. laptop + phone). Recording continues as long as >= 1 client is on the AP; the last client to disconnect triggers the pause.
- Phone connects without ever loading the page. We pause based on AP station count, not page state, so this still counts as "connected." For stricter behavior, switch to a JS heartbeat. Open question.

## Why FFT (vs. averaged downsampling)

We had originally planned 50 Hz -> 5 Hz averaged writes for v0.2. The team's call: that throws away the high-frequency content (loading-rate spikes, heel-strike transients) which is exactly the injury signal. The FFT keeps the spectrum, and a separate outlier buffer captures the actual peak events.

Net: averaged downsampling is **replaced** by FFT coefficients + an outlier buffer in v0.2.

## Implementation sketch (firmware, rough)

- New module `solesense_fft.h/cpp`: maintains a sliding-window or recursive incremental FFT (Goertzel for individual bins is one option; a true sliding-DFT is another). Capacity 3000 coefficients.
- New module `solesense_outliers.h/cpp`: fixed-capacity heap; insert with eviction.
- New module `solesense_storage.h/cpp`: multi-slot writer; load-newest-valid on boot.
- `takeSample()` change: instead of formatting a CSV row -> ring buffer -> file, push the sample into the FFT and the outlier detector.
- `loop()` change: in addition to draining `gNewSample`, call `flushSnapshot()` every 3 s.
- New routes per the table above; deprecate `/data.csv` raw streaming.

## Decisions still open

These need a team conversation:

1. **Sample rate**: 50 Hz (current) or 100 Hz? The "50 Hz is standard" argument has support, but other devices (Pedar-X, Moticon OpenGO) sample at 100 Hz internally. With FFT-based storage, the cost of a higher rate is just more compute, not more flash. Lean toward 100 Hz unless the CPU budget is too tight.
2. **FFT type**: full DFT, sliding-DFT, Goertzel, or Welch's method? Each has different RAM/CPU/accuracy tradeoffs. Needs a numerical-methods sanity check -- possibly worth a 1-day prototype.
3. **3000 coefficient count**: an arbitrary upper bound from the discussion. The real number depends on sample rate and target error rate, and is probably much smaller in practice (e.g. 256-512 bins capture everything below 25 Hz at a 50 Hz sample rate).
4. **Slot count and flush interval**: 10 slots x 3 s = 30 s recoverable. Adequate, or do we want longer?
5. **Outlier definition**: sigma threshold? Peak-of-derivative? Domain-specific (e.g. heel-strike acceleration peak)? Pin this down before implementation.
6. **Pause trigger**: AP station count (current plan) or explicit JS heartbeat? Station count is simpler but treats "client on AP, not viewing page" as "connected."
7. **Time sync**: decided -- duration is read from the latest valid flash slot, not from `millis()`. No wall-clock RTC needed unless runs span deep-sleep, in which case slot timestamps would need to be deep-sleep-resilient (RTC, or `boot_count` + relative offset).

## What this means for the team

- **Firmware**: adds the three new modules above; this is the biggest piece of work.
- **Frontend**: simpler, not more complex. The 5 Hz polling JS goes away, the `sensorData` array goes away, and CSV export goes away. The page just renders what `/api/run-state` and `/api/run-report` return.
- **Hardware/electrical**: no change.
- **Mechanical**: no change.

## References

- Team discussion 2026-05-06 (transcribed via UniScribe).
- Choi et al. (2024) for context on why averaged FSR data feeding ML models works -- though we go further here, using a spectral representation instead of time-domain averages.

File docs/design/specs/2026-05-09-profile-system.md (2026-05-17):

# Profile / Auth System -- Design Spec

> Status: implementation in progress (2026-05-09).

## Why

Today, anyone connected to the `SoleSense` WiFi AP can hit `POST /api/start` and record a run. There is no notion of who recorded it. Two practical problems:

1. **Privacy / fairness.** A stranger walking past the device can join the AP and overwrite an in-progress run.
2. **Body-weight calibration.** The FSR-jerk -> BW/s loading-rate conversion currently assumes 70 kg. Real BW/s scales by `70 / actual_kg`, so without per-user body weight the number is a placeholder.

Both are solved by a per-user profile system stored on-device in NVS.

## Scope

**In scope (this iteration):**
- On-device user accounts: username + PIN, hashed and stored in NVS.
- Login -> session token, passed in the `Authorization: Bearer ...` header on protected endpoints.
- Per-user `body_kg` field used in the loading-rate calc.
- Frontend login screen that blocks the rest of the UI until logged in.
- "Owner" model: the first registration claims the device. Subsequent registrations are walk-up self-signup (the shared WiFi password is the access gate), capped by `MAX_USERS = 50` and a 3-per-60-s sliding-window rate limit.

**Out of scope:**
- Multi-device sync -- there's no internet and no cloud.
- Email / password reset -- PIN reset is via the USB-serial `factory_reset` command only.
- Multi-session -- exactly one session-token slot in RAM at a time.
- Per-run history per user -- added in a later iteration.

## Threat model

We are protecting against:
- A guest joining the AP and starting or stopping runs that aren't theirs.
- Someone reading the LittleFS data partition off a stolen device and recovering PINs (so we hash + salt).

We are NOT protecting against:
- Someone with USB access -- they can re-flash firmware and bypass everything; physical access wins.
- Someone with prolonged WiFi access brute-forcing a 4-digit PIN. We add a simple rate limit (3 wrong -> 30 s lockout) to slow this down, not stop it.

## Storage (NVS)

Namespace: `solesense_auth`. Per-user data is stored as four flat keys, each prefixed by a single-character type tag. The `Preferences` library caps key length at 15 chars, so `<tag>_<username>` stays in budget for a 13-char username.

| Key | Type | Notes |
|---|---|---|
| `s_<u>` | bytes(16) | per-user random salt |
| `h_<u>` | bytes(32) | SHA-256(pin || salt) |
| `w_<u>` | float | body_kg, for loading-rate BW/s calc |
| `t_<u>` | float | height_cm, for stride-length + estimated-speed derivation |
| `owner_user` | string | username of the device owner |
| `uc` | u16 | total user count (incremented atomically on each register) |

About 250 B per user with NVS overhead. The 24 KB default NVS partition fits 50 users comfortably; the cap is set by `MAX_USERS`, not by capacity.

## Session model

One slot, RAM only:

```c
struct Session {
    bool      active;
    char      username[32];
    char      token_hex[65];  // 32 random bytes hex-encoded + null
    uint32_t  expires_ms;     // millis() rollover-aware
    float     body_kg;        // cached at login
    float     height_cm;      // cached at login (Cavanagh & Williams stride math)
} gSession;
```

The token is 32 random bytes from `esp_random()`. Default expiry: 30 minutes after the last protected request (idle timeout, refreshed on each successful auth check).

Logout clears the slot. Re-login replaces it.

## API

### Public

| Method | Path | Notes |
|---|---|---|
| `GET`  | `/` | static files |
| `GET`  | `/api/device` | identity, AP discovery |
| `GET`  | `/api/auth/state` | `{ ownerExists, sessionActive, username, userCount, maxUsers }` |
| `POST` | `/api/auth/register` | first call claims the device; subsequent calls are walk-up self-signup, capped by `MAX_USERS` + a 3-per-60-s rate limit |
| `POST` | `/api/auth/login` | `{ username, pin }` -> `{ token, body_kg, height_cm, username }` |

### Protected (require valid token)

| Method | Path | Notes |
|---|---|---|
| `POST` | `/api/auth/logout` | clear session |
| `GET`  | `/api/auth/profile` | current profile (`username`, `body_kg`, `height_cm`) |
| `POST` | `/api/auth/profile` | edit `body_kg` and/or `height_cm` without re-registering |
| `POST` | `/api/start` | start recording |
| `POST` | `/api/stop` | stop recording |
| `POST` | `/api/calibrate/zero` | FSR zero |
| `POST` | `/api/calibrate/imu` | IMU zero |
| `POST` | `/api/data/clear` | wipe the run-snapshot ring buffer |
| `POST` | `/api/sleep` | deep sleep |

### Read-only diagnostic (intentionally still public)

`GET /api/sensor`, `GET /api/run-state`, `GET /api/run-report`, `GET /api/run-spectrum`, `GET /api/run-outliers`. These don't change device state and are useful as "is the device alive" probes.

## Failure modes

| Case | Response |
|---|---|
| Protected route, no `Authorization` header | `401 Unauthorized` |
| Token invalid or expired | `401 Unauthorized`, frontend kicks back to login |
| Login with wrong PIN, 3 times in a 60 s window | `429 Too Many Requests`, lock the username for 30 s |
| Register over the `MAX_USERS` cap | `507 Insufficient Storage` |
| Register more than 3 times in a 60 s window | `429 Too Many Requests` |
| NVS write failure | `400 Bad Request` (after atomic rollback of any partial state) |
| Register with invalid body_kg (< 25 or > 250 kg) | `400 Bad Request` |
| Register with invalid height_cm (< 100 or > 250 cm) | `400 Bad Request` |

## Frontend changes

The login screen is the new first screen. The token in `localStorage` survives reload. On any 401 response, the frontend wipes localStorage and bounces back to login.

The loading-rate display still reads `r.loadingRate`, but the firmware now divides by the logged-in user's body weight, so the displayed BW/s is honest per-user.

## Implementation order

1. `auth.h/cpp` -- NVS helpers, SHA-256, session struct, token generation.
2. New HTTP routes (`/api/auth/*`).
3. `require_auth()` middleware applied to protected routes.
4. Wire body weight into the loading-rate calc (replaces the hardcoded 70 kg).
5. Frontend: login screen, localStorage token, Authorization header on every protected fetch.
6. Edge cases: PIN-attempt rate limit, 401 handler in the frontend, factory-reset over USB serial.

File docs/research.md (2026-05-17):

# SoleSense Research Basis

Peer-reviewed sources that justify SoleSense's sampling rate, injury-flag thresholds, FSR sensor placement, and the commercial benchmark we compare against.

## Sampling rate

The firmware samples at 500 Hz internally. The lower bounds in the literature target walking-gait analysis; we sample faster because impact rising edges during running are 5-20 ms wide and need oversampling for accurate loading-rate math.

- **Antonsson & Mann (1985)** -- *Journal of Biomechanics.* GRF signal bandwidth tops out at ~20 Hz, so the Nyquist minimum is 40 Hz.
- **Winter (2009)** -- *Biomechanics of Human Movement.* 50 Hz is the standard clinical rate for gait analysis.
- **Rosenbaum & Becker (1997)** -- *Clinical Biomechanics.* Above ~50 Hz the captured signal includes material vibration and footwear noise rather than biomechanics. We sample at 500 Hz for impact-edge resolution and low-pass-filter in analysis; raw rate is not the same as analysis bandwidth.

## Injury-flag thresholds

The injury flags surfaced by the report screen use the following research-backed cutoffs.

| Flag | Cutoff | Source |
|---|---|---|
| Low cadence | < 160 spm | Heiderscheit et al. (2011), *Medicine & Science in Sports & Exercise* |
| Heel striking | heel/forefoot load ratio > 65 % AND heel-ball delta > 10 | Lieberman et al. (2010), *Nature* |
| High impact rate | loading rate > 80 BW/s | Milner et al. (2006), *MSSE*; Davis et al. (2016), *BJSM* |
| Overpronation | gyro_x running mean > 15 deg/s | Souza (2016), *Journal of Orthopaedic & Sports Physical Therapy* |
| Supination | gyro_x running mean < -8 deg/s | Souza (2016) |
| Medial / lateral asymmetry | > 10 % difference | Zifchock et al. (2006), *Clinical Biomechanics* |
| FSR saturation (diagnostic, not a risk) | peak avg-channel ADC > 3500 | --- |

Ground contact time is **computed and displayed** but not flagged in this version -- it appears in the run report as a metric (with a 250-300 ms typical range note), not as a thresholded injury flag. Adding a `gct_long` flag is a planned follow-up.

## FSR sensor placement

The 6-sensor layout (3-zone medial/lateral: 2 heel + 2 midfoot + 2 forefoot) is adapted from validated configurations in the literature.

- **Choi et al. (2024)** -- *Sensors (MDPI)*, "Calibrating Low-Cost Smart Insole Sensors with Recurrent Neural Networks for Accurate Prediction of Center of Pressure." A six-FSR insole validated against the Tekscan F-Scan (~$20K commercial system). Routing the FSR data through an RNN/LSTM improves GRF/CoP prediction accuracy by 30%+. SoleSense's layout matches their validated zone configuration, with sensor E moved next to F so both sit at the heel.
- **Claverie et al. (2016)** -- *Medical Engineering & Physics.* Discrete-sensor distribution strategies for plantar-pressure analysis.

## Height-based stride normalization

Users provide their height at signup. The report uses it to derive an estimated stride length and an estimated speed, and the AI Coach receives it in the payload so its analysis can be calibrated to the runner's stature.

- **Cavanagh & Williams (1982)** -- *Medicine & Science in Sports & Exercise* 14(1):30, "The effect of stride length variation on oxygen uptake during distance running." Empirically, **distance-running stride length averages ~0.42 x standing height** at freely-chosen pace, with a natural range of 0.40-0.45 x height. SoleSense estimates stride from this factor, so the displayed value should be read as *what's typical for a runner your height*, not as a measurement.
- **Bramble & Lieberman (2004)** -- *Nature* 432:345, "Endurance running and the evolution of *Homo*." Locomotor parameters (stride length, contact time, vertical oscillation) scale with leg length, which is approximately 0.53 x standing height in adults. This provides the theoretical basis for height-normalizing biomechanical comparisons across runners of different sizes.
- **Cavagna, Franzetti, Heglund & Willems (1988)** -- *Journal of Physiology* 399:81, "The determinants of the step frequency in running, trotting and hopping in man and other vertebrates." Step frequency at a given speed scales with leg length, so shorter runners run at higher cadence than taller runners at identical pace. The 170-180 spm "healthy cadence" guideline applies to adults of typical height (~170-180 cm); shorter or taller runners naturally sit slightly above or below that band.
- **Hreljac & Marshall (2000)** -- *Journal of Biomechanics* 33:783, "Algorithms to determine event timing during normal walking using kinematic data." Contact-time interpretation also depends on leg length; the >300 ms "long GCT" threshold is most meaningful when read alongside the runner's stature.

**How SoleSense uses height today:**

1. **Estimated stride length** (`m-stride` on the report): `0.42 x height_m`, per Cavanagh & Williams (1982).
2. **Estimated running speed** (`m-speed` on the report): `cadence_spm x stride_m / 60`, expressed in km/h. Approximate for steady-pace running.
3. **AI Coach payload** (`user.height_cm`): the Cloudflare Worker forwards height to the LLM so its analysis can note things like "your cadence is high *for your height*" instead of treating 170 spm as universal.

**What height is *not* used for** (deliberate -- needs more rigorous validation first):

- Adjusting the injury-flag thresholds themselves (cadence < 160 spm, loading > 80 BW/s, etc.). These remain the universal research-backed cutoffs; the AI Coach can contextualize them by stature, but the rule-based flags don't shift.

## Commercial benchmarks

Systems SoleSense is compared against in the price-vs-fidelity tradeoff.

| Device | Sample rate | Notes |
|---|---|---|
| Pedar-X (Novel GmbH) | 100 Hz internal, 50 Hz output | Lab-grade reference |
| Moticon OpenGO | 100 Hz internal, 25 Hz logged | Consumer wearable |
| Tekscan F-Scan | 100 Hz | Clinical reference, ~$20,000 |

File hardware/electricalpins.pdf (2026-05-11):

MCU - XIAO ESP32C3

Seeed | Meaning | Diagram description
VBus | 5V | Connect to batteries
3V3 | 3V3 (3.3 V) | P_IMU, 3.3 Volts, connect to IMU
D0 | Analog | C3_anlg_A
D1 | Analog | C3_anlg_B
D2 | Analog | C3_anlg_C
D4 | SDA | SDA, on IMU
D5 | SCL | SCL, on IMU
D6 | Digital | Int, connect to IMU
D7 | Digital | P1, FSR set 1
D8 | Digital | P2, FSR set 2
D9 | Digital | P3, FSR set 3
GND | Ground | Ground

IMU - MPU 6050

MPU 6050 | Meaning | Diagram Description
VCC | 3V3 (3.3V) | P_IMU, Connect to MCU
SDA | SDA | SDA, connect to MCU
SCL | SCL | SCL, connect to MCU
INT | Int | Int, connect to MCU
GND | GND | GND/Total_GND

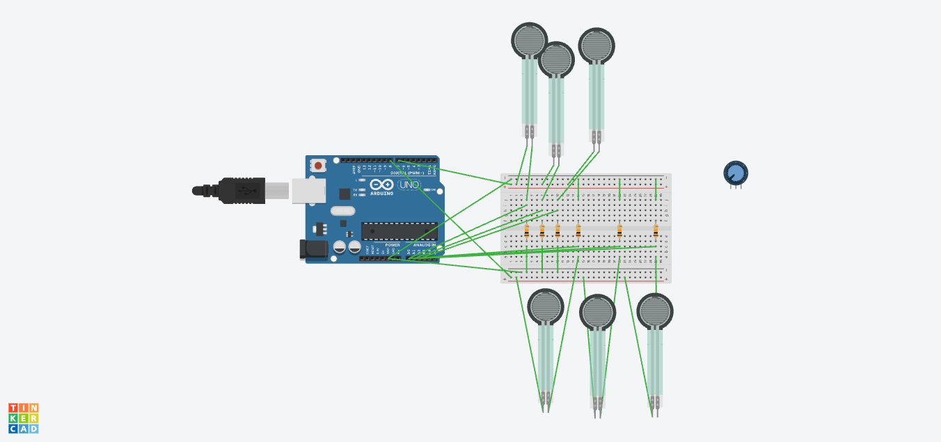
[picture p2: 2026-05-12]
hardware/simulations/tinkercad-fsr-demo/solesense-fsr-matrix-scan.png

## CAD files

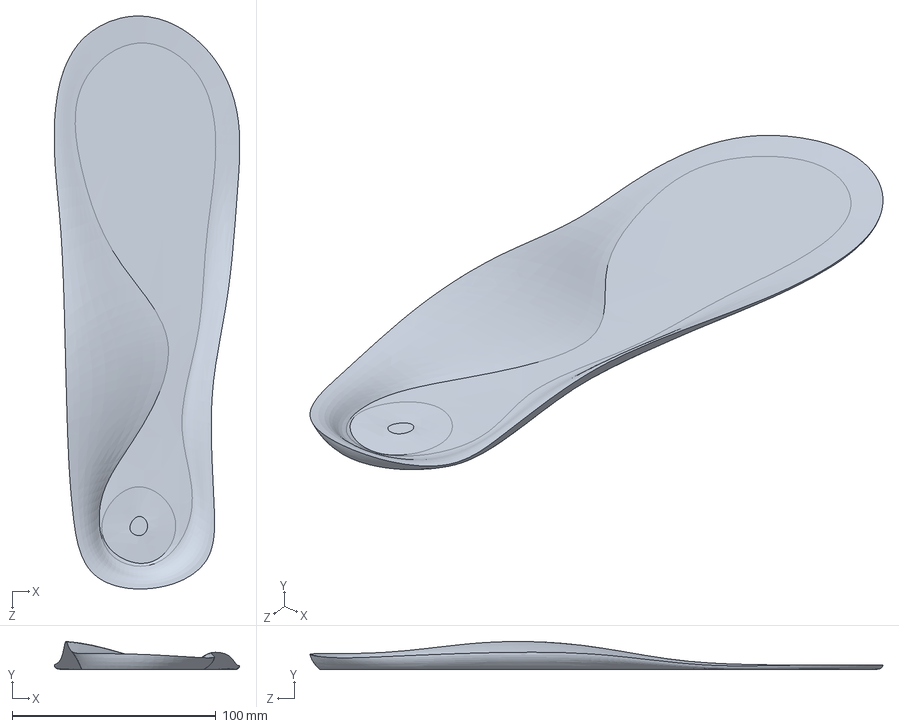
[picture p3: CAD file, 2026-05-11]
hardware/cad/hopefullyfinalsolesense.SLDPRT
91.1 x 13.8 x 281.6 mm

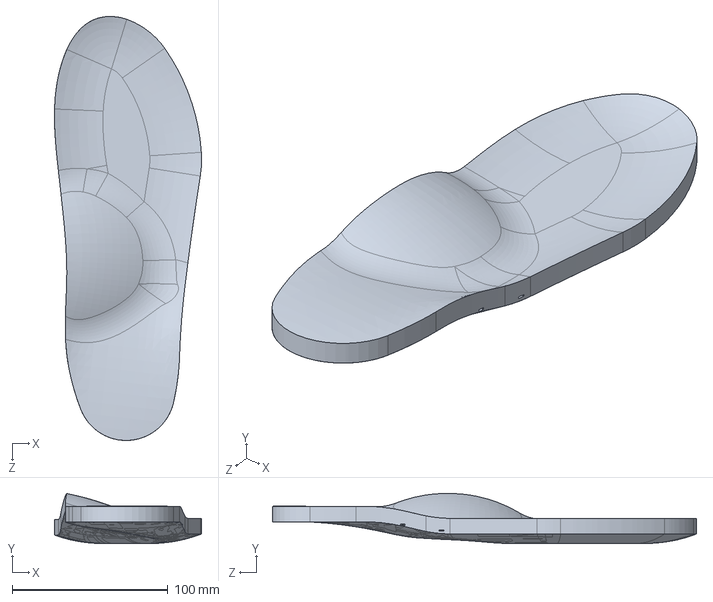
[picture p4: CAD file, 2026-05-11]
hardware/cad/final Sole Sense 1.SLDPRT
94.6 x 32.2 x 272.4 mm

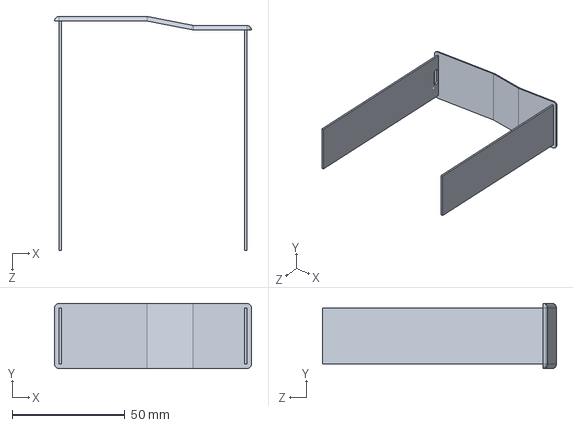
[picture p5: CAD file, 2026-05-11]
hardware/cad/New New New Lid.SLDPRT
87.5 x 29.0 x 104.0 mm

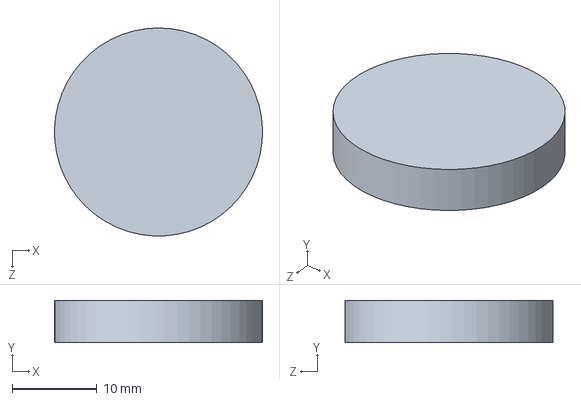
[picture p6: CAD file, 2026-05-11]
hardware/cad/New New Battery.SLDPRT
24.5 x 5.00 x 24.5 mm

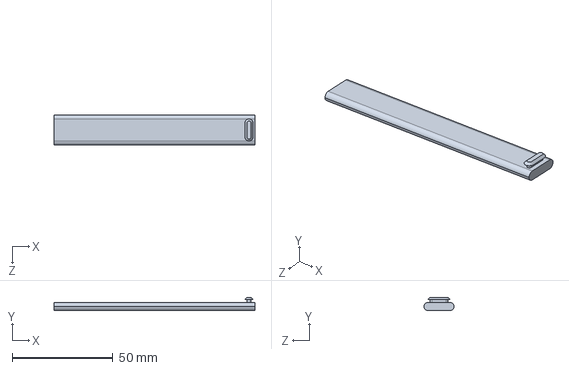
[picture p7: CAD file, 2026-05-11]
hardware/cad/TPU Strap.SLDPRT
100.0 x 6.50 x 15.0 mm

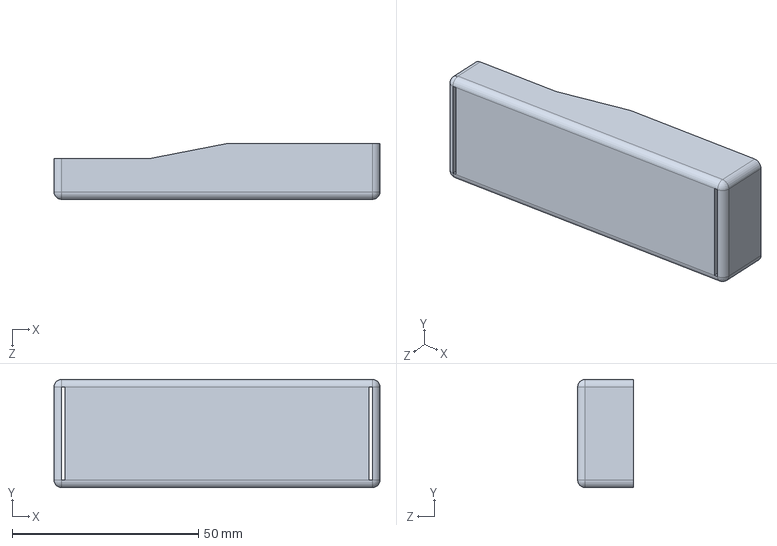
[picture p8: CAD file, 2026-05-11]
hardware/cad/New Compartment Housing.SLDPRT
87.5 x 29.0 x 15.0 mm

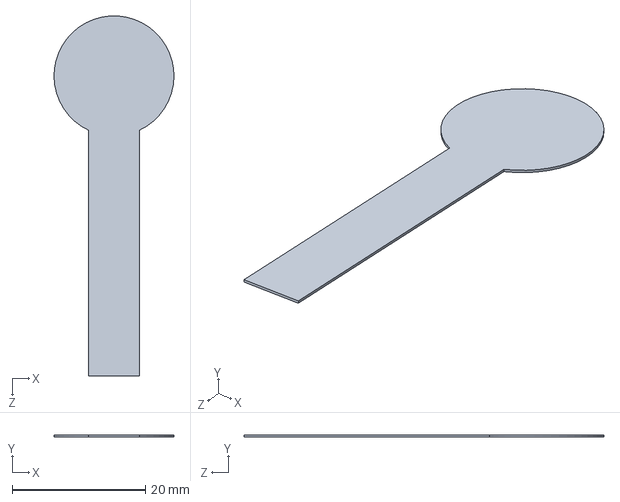
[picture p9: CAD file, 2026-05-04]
hardware/cad/FSR Cutout.SLDPRT
18.0 x 0.3 x 54.0 mm

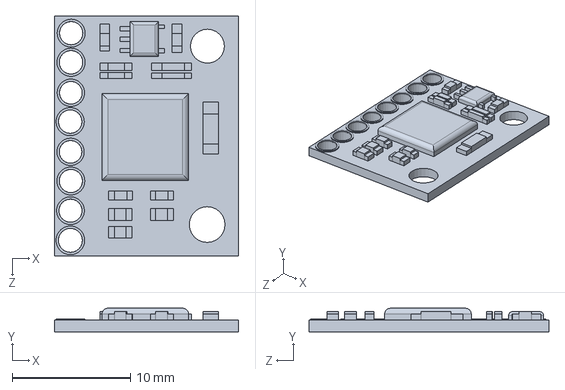
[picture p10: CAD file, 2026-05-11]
hardware/cad/MPU6050 v2 grabcad.SLDPRT
15.6 x 2.00 x 20.3 mm

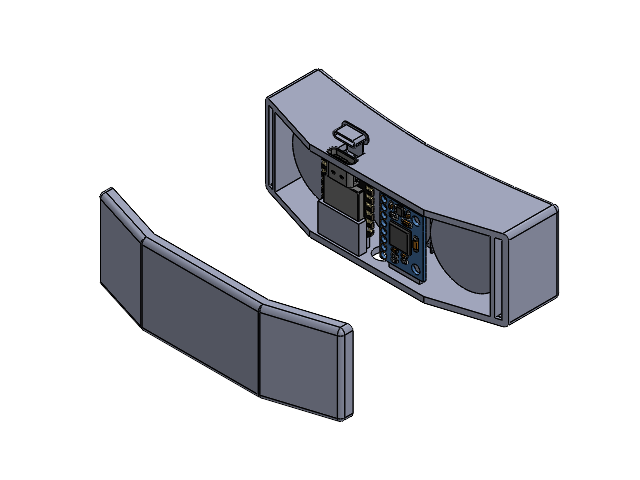
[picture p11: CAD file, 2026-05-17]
hardware/Updated New Assembly without Holder James Edit.SLDASM
BOSS-EXTRUDE14_8_.step
BOSS-EXTRUDE7_4_.step
BOSS-EXTRUDE7_3_.step
BOSS-EXTRUDE14_4_.step
BOSS-EXTRUDE14_2_.step
BOSS-EXTRUDE14_11_.step
BOSS-EXTRUDE7_7_.step
BOSS-EXTRUDE14_9_.step
BOSS-EXTRUDE14_3_.step
BOSS-EXTRUDE14_7_.step
MIRROR2.step
BOSS-EXTRUDE14_5_.step
BOSS-EXTRUDE14_12_.step
BOSS-EXTRUDE7_8_.step
BOSS-EXTRUDE7_1_.step
BOSS-EXTRUDE14_10_.step
BOSS-EXTRUDE7_9_.step
BOSS-EXTRUDE14_6_.step
CHAMFER9.step
BOSS-EXTRUDE14_1_.step
BOSS-EXTRUDE7_6_.step
BOSS-EXTRUDE7_2_.step
CUT-EXTRUDE5.step
BOSS-EXTRUDE7_5_.step
U.FL Connector v1.step
Button (1).step x 2
Shield.step
eBom-FreeParts.step
MPU6050 v2 grabcad
New New New Lid
New Compartment Housing 1
New New Battery x 3

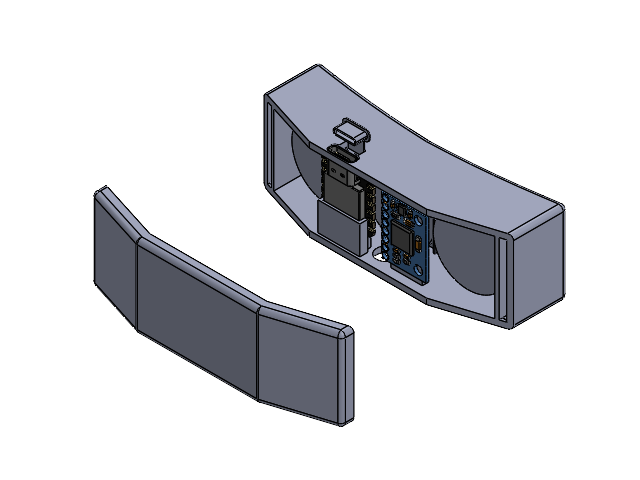
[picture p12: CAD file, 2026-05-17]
hardware/james prototype.SLDASM
BOSS-EXTRUDE14_8_.step
BOSS-EXTRUDE7_4_.step
BOSS-EXTRUDE7_3_.step
BOSS-EXTRUDE14_4_.step
BOSS-EXTRUDE14_2_.step
BOSS-EXTRUDE14_11_.step
BOSS-EXTRUDE7_7_.step
BOSS-EXTRUDE14_9_.step
BOSS-EXTRUDE14_3_.step
BOSS-EXTRUDE14_7_.step
MIRROR2.step
BOSS-EXTRUDE14_5_.step
BOSS-EXTRUDE14_12_.step
BOSS-EXTRUDE7_8_.step
BOSS-EXTRUDE7_1_.step
BOSS-EXTRUDE14_10_.step
BOSS-EXTRUDE7_9_.step
BOSS-EXTRUDE14_6_.step
CHAMFER9.step
BOSS-EXTRUDE14_1_.step
BOSS-EXTRUDE7_6_.step
BOSS-EXTRUDE7_2_.step
CUT-EXTRUDE5.step
BOSS-EXTRUDE7_5_.step
U.FL Connector v1.step
Button (1).step x 2
Shield.step
eBom-FreeParts.step
MPU6050 v2 grabcad
New New New Lid
New Compartment Housing 1
New New Battery x 3

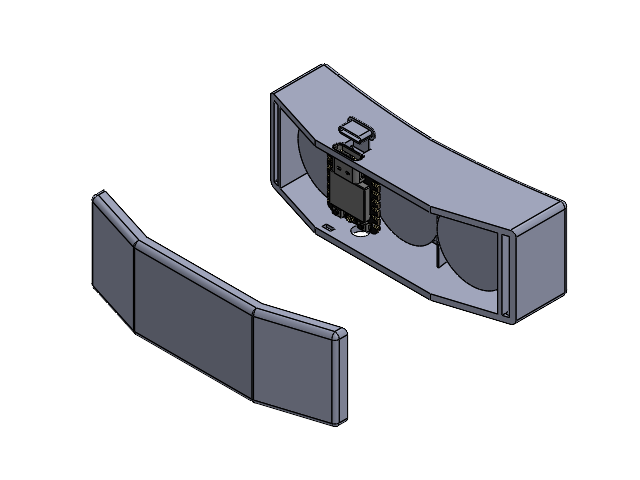
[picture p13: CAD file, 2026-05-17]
hardware/Updated New Assembly without Holder (1).SLDASM
BOSS-EXTRUDE14_8_.step
BOSS-EXTRUDE7_4_.step
BOSS-EXTRUDE7_3_.step
BOSS-EXTRUDE14_4_.step
BOSS-EXTRUDE14_2_.step
BOSS-EXTRUDE14_11_.step
BOSS-EXTRUDE7_7_.step
BOSS-EXTRUDE14_9_.step
BOSS-EXTRUDE14_3_.step
BOSS-EXTRUDE14_7_.step
MIRROR2.step
BOSS-EXTRUDE14_5_.step
BOSS-EXTRUDE14_12_.step
BOSS-EXTRUDE7_8_.step
BOSS-EXTRUDE7_1_.step
BOSS-EXTRUDE14_10_.step
BOSS-EXTRUDE7_9_.step
BOSS-EXTRUDE14_6_.step
CHAMFER9.step
BOSS-EXTRUDE14_1_.step
BOSS-EXTRUDE7_6_.step
BOSS-EXTRUDE7_2_.step
CUT-EXTRUDE5.step
BOSS-EXTRUDE7_5_.step
U.FL Connector v1.step
Button (1).step x 2
Shield.step
eBom-FreeParts.step
MPU6050 v2 grabcad
New New New Lid
New Compartment Housing 1
New New Battery x 3

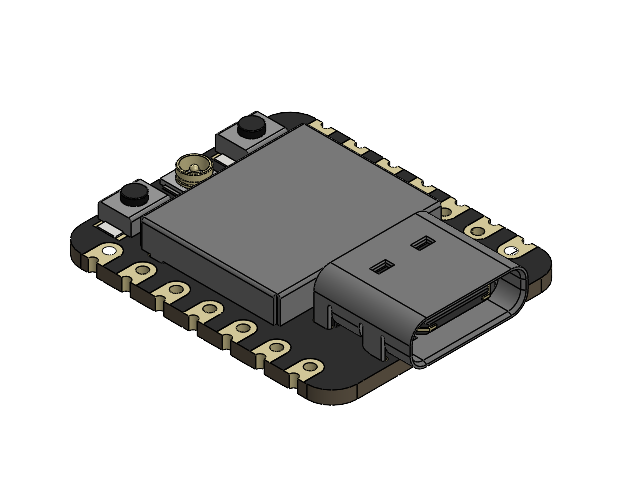
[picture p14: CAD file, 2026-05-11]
hardware/cad/Seeed Studio XIAO-ESP32-C3.SLDASM
BOSS-EXTRUDE14_8_.step
BOSS-EXTRUDE7_4_.step
BOSS-EXTRUDE7_3_.step
BOSS-EXTRUDE14_4_.step
BOSS-EXTRUDE14_2_.step
BOSS-EXTRUDE14_11_.step
BOSS-EXTRUDE7_7_.step
BOSS-EXTRUDE14_9_.step
BOSS-EXTRUDE14_3_.step
BOSS-EXTRUDE14_7_.step
MIRROR2.step
BOSS-EXTRUDE14_5_.step
BOSS-EXTRUDE14_12_.step
BOSS-EXTRUDE7_8_.step
BOSS-EXTRUDE7_1_.step
BOSS-EXTRUDE14_10_.step
BOSS-EXTRUDE7_9_.step
BOSS-EXTRUDE14_6_.step
CHAMFER9.step
BOSS-EXTRUDE14_1_.step
BOSS-EXTRUDE7_6_.step
BOSS-EXTRUDE7_2_.step
CUT-EXTRUDE5.step
BOSS-EXTRUDE7_5_.step
U.FL Connector v1.step
Button (1).step x 2
Shield.step
eBom-FreeParts.step

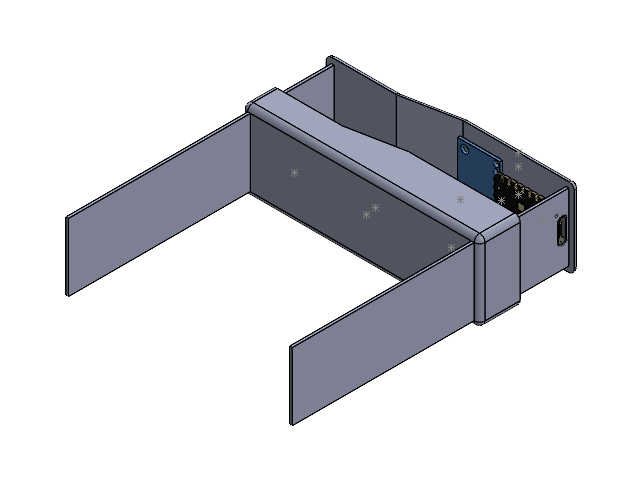
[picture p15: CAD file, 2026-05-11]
hardware/cad/Updated New Assembly without Holder.SLDASM
New Compartment Housing
BOSS-EXTRUDE14_8_.step
BOSS-EXTRUDE7_4_.step
BOSS-EXTRUDE7_3_.step
BOSS-EXTRUDE14_4_.step
BOSS-EXTRUDE14_2_.step
BOSS-EXTRUDE14_11_.step
BOSS-EXTRUDE7_7_.step
BOSS-EXTRUDE14_9_.step
BOSS-EXTRUDE14_3_.step
BOSS-EXTRUDE14_7_.step
MIRROR2.step
BOSS-EXTRUDE14_5_.step
BOSS-EXTRUDE14_12_.step
BOSS-EXTRUDE7_8_.step
BOSS-EXTRUDE7_1_.step
BOSS-EXTRUDE14_10_.step
BOSS-EXTRUDE7_9_.step
BOSS-EXTRUDE14_6_.step
CHAMFER9.step
BOSS-EXTRUDE14_1_.step
BOSS-EXTRUDE7_6_.step
BOSS-EXTRUDE7_2_.step
CUT-EXTRUDE5.step
BOSS-EXTRUDE7_5_.step
U.FL Connector v1.step
Button (1).step x 2
Shield.step
eBom-FreeParts.step
MPU6050 v2 grabcad
New New Battery x 3
New New New Lid

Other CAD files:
hardware/3d printing/Housing with strap.gcode.3mf
hardware/3d printing/Lid (goes with housing).gcode.3mf

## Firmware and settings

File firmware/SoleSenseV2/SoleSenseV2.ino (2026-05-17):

// SoleSense v0.2 main sketch.
// Architecture: docs/design/specs/2026-05-06-v0.2-data-architecture.md

#include <Arduino.h>
#include <WiFi.h>
#include <Wire.h>
#include <LittleFS.h>
#include <ESPAsyncWebServer.h>
#include <ESPmDNS.h>
#include <esp_sleep.h>
#include <math.h>

#include "config.h"
#include "state.h"
#include "sensors.h"
#include "fft.h"
#include "outliers.h"
#include "stats.h"
#include "storage.h"
#include "http_routes.h"
#include "auth.h"

AsyncWebServer server(HTTP_PORT);

// -- 500 Hz hardware-timer ISR ------------------------------------------------
hw_timer_t* gTimer = nullptr;

void IRAM_ATTR onSampleTick() {
  gNewSample = true;
}

static void start_sample_timer() {
  gTimer = timerBegin(1000000);                          // 1 MHz tick
  if (!gTimer) { Serial.println("[Timer] alloc FAILED"); return; }
  timerAttachInterrupt(gTimer, &onSampleTick);
  timerAlarm(gTimer, SAMPLE_PERIOD_US, true, 0);
}

// -- Standby + foot-press / motion wake ---------------------------------------
//
// The housing seals over the on-board BOOT button, which means a true deep
// sleep with GPIO9 as the wake source would brick the device until someone
// pried the case open. The ESP32-C3 only exposes GPIO0-5 as RTC-capable
// pins, and all of ours are tied up (3x shared ADCs + 2x I2C), so we
// can't tie the MPU-6050 INT line to a deep-sleep wake pin either.
//
// Workaround: light sleep with a 1.5 s RTC timer. On each wake we briefly
// power one FSR set, take three ADC reads, then check the IMU acceleration
// magnitude (belt-and-suspenders -- either gesture wakes us). If anything
// triggers -> full wake. If not -> back to sleep. Total active time per
// cycle is ~900 us out of 1.5 s = ~0.06% duty cycle, sitting around the
// ~150 uA light-sleep floor of the C3.
//
// We also tear WiFi down before entering the loop to save the ~30 mA the
// soft-AP otherwise draws continuously, and bring it back up after wake.
//
// On wake, gWakeGraceExpiresMs is set to (now + WAKE_GRACE_MS). loop() then
// re-enters standby if no phone connects within that window -- this catches
// "the insole got squished in your gym bag" false wakes without leaving
// the radio on indefinitely.
static const uint32_t WAKE_GRACE_MS = 60000;   // 60s to connect before back to standby
static volatile uint32_t sWakeGraceExpiresMs = 0;

// Brief IMU accel-magnitude read for the wake-check loop. Returns the
// magnitude in m/s^2 (or NAN if the I2C transaction failed). At rest the
// magnitude reads ~9.81; any nontrivial motion shifts it.
static float read_imu_accel_magnitude() {
  Wire.beginTransmission(MPU6050_ADDR);
  Wire.write(0x3B);                                 // ACCEL_XOUT_H
  if (Wire.endTransmission(false) != 0) return NAN;
  if (Wire.requestFrom((uint8_t)MPU6050_ADDR, (uint8_t)6) != 6) return NAN;
  int16_t rax = (Wire.read() << 8) | Wire.read();
  int16_t ray = (Wire.read() << 8) | Wire.read();
  int16_t raz = (Wire.read() << 8) | Wire.read();
  float ax = (rax / ACCEL_LSB_PER_G) * G_TO_MS2;
  float ay = (ray / ACCEL_LSB_PER_G) * G_TO_MS2;
  float az = (raz / ACCEL_LSB_PER_G) * G_TO_MS2;
  return sqrtf(ax*ax + ay*ay + az*az);
}

static void enter_foot_press_standby() {
  Serial.println("[Standby] wake armed -- step on insole OR pick it up to wake");
  Serial.flush();

  // Drain any in-flight HTTP requests before tearing the WiFi stack down --
  // same race that bit us with the old deep-sleep teardown.
  delay(500);

  // Park both FSR sets LOW (defensive -- avoids any phantom current paths
  // while the chip is asleep).
  pinMode(PIN_PWR_SET1, OUTPUT);
  pinMode(PIN_PWR_SET2, OUTPUT);
  digitalWrite(PIN_PWR_SET1, LOW);
  digitalWrite(PIN_PWR_SET2, LOW);

  // Drop the WiFi AP so the radio stops drawing ~30 mA. Light sleep alone
  // would only get us "modem sleep" which still costs ~15 mA average.
  WiFi.softAPdisconnect(true);
  WiFi.mode(WIFI_OFF);

  // Wake-detection loop. esp_light_sleep_start() preserves RAM and CPU
  // state, so when we wake from the timer we just continue executing
  // the next instruction.
  const uint32_t SLEEP_US                = 1500000;  // 1.5 s between checks
  const int      WAKE_FSR_THRESHOLD      = 250;       // ADC counts above unloaded baseline
  const float    WAKE_MOTION_DELTA_MS2   = 2.0f;      // |accel| - 1g threshold (~0.2g)
  uint32_t       cycle_count             = 0;
  const char*    wake_cause              = "?";

  while (true) {
    esp_sleep_enable_timer_wakeup(SLEEP_US);
    esp_light_sleep_start();
    cycle_count++;

    // -- 1. Foot-press check (Set 1) ------------------------------------
    digitalWrite(PIN_PWR_SET1, HIGH);
    delayMicroseconds(200);
    int a = analogRead(PIN_ADC_A);
    int b = analogRead(PIN_ADC_B);
    int c = analogRead(PIN_ADC_C);
    digitalWrite(PIN_PWR_SET1, LOW);
    int max_a = a > b ? (a > c ? a : c) : (b > c ? b : c);
    if (max_a > WAKE_FSR_THRESHOLD) { wake_cause = "foot-press (set1)"; break; }

    // -- 2. Foot-press check (Set 2) ------------------------------------
    digitalWrite(PIN_PWR_SET2, HIGH);
    delayMicroseconds(200);
    int d = analogRead(PIN_ADC_A);
    int e = analogRead(PIN_ADC_B);
    int f = analogRead(PIN_ADC_C);
    digitalWrite(PIN_PWR_SET2, LOW);
    int max_b = d > e ? (d > f ? d : f) : (e > f ? e : f);
    if (max_b > WAKE_FSR_THRESHOLD) { wake_cause = "foot-press (set2)"; break; }

    // -- 3. IMU motion check --------------------------------------------
    // At rest the accel magnitude reads ~9.81 (gravity only). Picking the
    // insole up, shaking it, or any nontrivial movement shifts it. The
    // ~0.2g delta threshold is loose enough to catch a deliberate "pick
    // it up" gesture and tight enough to ignore bench-vibration noise.
    float mag = read_imu_accel_magnitude();
    if (!isnan(mag) && fabsf(mag - G_TO_MS2) > WAKE_MOTION_DELTA_MS2) {
      wake_cause = "motion (IMU)";
      break;
    }
  }

  Serial.printf("[Wake] cause: %s, cycles=%u (~%.1fs of standby)\n",
                wake_cause, (unsigned)cycle_count,
                cycle_count * (SLEEP_US / 1000000.0f));

  // Bring the WiFi AP back up. mDNS has to be re-bound since its task tied
  // to the old WiFi event-loop state.
  WiFi.mode(WIFI_AP);
  WiFi.softAP(SS_AP_SSID, SS_AP_PASS);
  IPAddress ip = WiFi.softAPIP();
  Serial.printf("[Wake] WiFi AP '%s' restored at %s\n", SS_AP_SSID, ip.toString().c_str());

  MDNS.end();
  if (MDNS.begin("solesense")) {
    MDNS.addService("http", "tcp", 80);
    Serial.println("[Wake] mDNS solesense.local rebound");
  }

  // Arm the wake-grace window. If no phone connects within 60s of this
  // moment, loop() will trigger another standby entry (false-wake handler).
  sWakeGraceExpiresMs = millis() + WAKE_GRACE_MS;
}

// Called from loop() each tick after a wake. If a phone connects we cancel
// the grace timer; if it expires with no connection, we go back to standby.
static void check_wake_grace_window() {
  if (sWakeGraceExpiresMs == 0) return;            // grace not armed
  uint32_t now = millis();
  uint8_t  clients = WiFi.softAPgetStationNum();
  if (clients > 0) {
    // Phone connected -- the wake was intentional. Cancel grace.
    Serial.println("[Wake] client connected within grace, staying up");
    sWakeGraceExpiresMs = 0;
  } else if ((int32_t)(now - sWakeGraceExpiresMs) >= 0) {
    // Grace expired with nobody home. Most likely a false wake from the
    // insole rattling in a bag. Re-enter standby instead of burning the
    // radio for nothing.
    Serial.println("[Standby] no connection within grace window -- back to standby");
    sWakeGraceExpiresMs = 0;
    gSleepRequested = true;                         // serviced on next loop tick
  }
}

// Per-sample processing. Vertical IMU jerk and FSR-jerk are tracked as
// fusion signals alongside the FSR-based step detector. The "has prev"
// flags must be cleared whenever sampling pauses and resumes (Wi-Fi
// drop, iOS captive-portal probe, etc.) -- otherwise the next call
// computes (now - prev) over a seconds-long gap and produces a giant
// spurious jerk that falsely fires the `high_loading` injury flag.
// state.cpp sets gResetSampleTracking on resume; we honor it here.
static float sPrevAccelZ  = 0.0f;
static bool  sJerkHasPrev = false;
static float sPrevAny     = 0.0f;
static bool  sAnyHasPrev  = false;

static void process_sample() {
  sensors_read_all();
  gSampleCount++;

  if (gResetSampleTracking) {
    sJerkHasPrev = false;
    sAnyHasPrev  = false;
    gResetSampleTracking = false;
  }

  // Vertical jerk: |accel_z| / t over the last sample interval.
  if (sJerkHasPrev) {
    constexpr float DT_S = 1.0f / (float)SAMPLE_RATE_HZ;
    float jerk = fabsf(gAccel[2] - sPrevAccelZ) / DT_S;
    if (jerk > gMaxJerkZ) gMaxJerkZ = jerk;
  }
  sPrevAccelZ  = gAccel[2];
  sJerkHasPrev = true;

  // Stack-allocating a 12-element float every 2 ms hits the cache, but it
  // also re-zeros on every call -- avoid by making it static-local.
  static float channelVal[N_CHANNELS_TOTAL];
  for (uint8_t i = 0; i < N_FSR; i++) channelVal[i] = (float)gFsr[i];
  channelVal[N_FSR + 0] = gAccel[0];
  channelVal[N_FSR + 1] = gAccel[1];
  channelVal[N_FSR + 2] = gAccel[2];
  channelVal[N_FSR + 3] = gGyro[0];
  channelVal[N_FSR + 4] = gGyro[1];
  channelVal[N_FSR + 5] = gGyro[2];

  float az_mean = 0.0f, az_stddev = 0.0f;
  for (uint8_t c = 0; c < N_CHANNELS_TOTAL; c++) {
    stats_update(c, channelVal[c]);
    float mean = stats_get_mean(c);
    float std  = stats_get_stddev(c);
    if (c == N_FSR + 2) { az_mean = mean; az_stddev = std; }

    // Outlier-first: a sample over the sigma threshold is captured to the
    // ring buffer but skipped from the FFT so impact spikes don't smear it.
    bool isOutlier = outliers_offer(gRunElapsedMs, c, channelVal[c], mean, std);
    if (!isOutlier) {
      fft_process_sample(c, channelVal[c], mean);
    }
  }

  // IMU sensor-fusion: connected iff accel_z has accumulated noise (a
  // disconnected MPU-6050 leaves gAccel pinned, so stddev stays exactly 0).
  float az = channelVal[N_FSR + 2];
  if (az_stddev > IMU_CONNECTED_STDDEV_FLOOR) gImuConnected = true;
  if (gImuConnected && fabsf(az - az_mean) > IMU_IMPACT_DELTA_MS2) {
    gLastImuImpactMs = gRunElapsedMs;
    gImuImpactCount++;
  }

  // Single FSR pass: total pressure for diagnostics, OR-gate max for the
  // step detector. Refractory window in state.cpp keeps a single stride from
  // counting heel->midfoot->forefoot as three strikes.
  float totalPressure = 0.0f;
  float anyZoneMax    = channelVal[0];
  for (uint8_t i = 0; i < N_FSR; i++) {
    totalPressure += channelVal[i];
    if (channelVal[i] > anyZoneMax) anyZoneMax = channelVal[i];
  }
  if (totalPressure > gMaxTotalPressure) gMaxTotalPressure = totalPressure;
  step_detector_update(anyZoneMax,
                       stats_get_mean(0),
                       stats_get_stddev(0),
                       gRunElapsedMs);

  // FSR-jerk loading rate: track per-sample d(anyZoneMax)/dt and keep the
  // peak. Same OR-gate: peak rate-of-rise wherever the impact lands counts.
  // sPrevAny/sAnyHasPrev are file-scope so they reset on pause/resume.
  if (sAnyHasPrev) {
    float jerk = (anyZoneMax - sPrevAny) * (float)SAMPLE_RATE_HZ;
    if (jerk > gMaxHeelJerk) gMaxHeelJerk = jerk;
  }
  sPrevAny    = anyZoneMax;
  sAnyHasPrev = true;
}

// -- setup() ------------------------------------------------------------------
void setup() {
  Serial.begin(115200);
  delay(200);
  Serial.println("=== SoleSense v0.2 booting ===");

  if (!LittleFS.begin()) {
    Serial.println("[FS] mount FAILED");
  } else {
    Serial.printf("[FS] Mounted - %u / %u bytes used\n",
                  (unsigned)LittleFS.usedBytes(), (unsigned)LittleFS.totalBytes());
  }

  pinMode(PIN_WAKE, INPUT_PULLUP);
  sensors_init();
  fft_init();
  outliers_reset();
  stats_reset();
  storage_init();
  state_init();
  auth_init();

  WiFi.softAP(SS_AP_SSID, SS_AP_PASS);
  IPAddress ip = WiFi.softAPIP();
  Serial.printf("[WiFi] AP '%s' up at %s\n", SS_AP_SSID, ip.toString().c_str());

  // mDNS: lets users on iOS/macOS visit http://solesense.local/ instead
  // of typing the IP. Doesn't trigger any captive-portal auto-popup --
  // it's a passive hostname resolver. Android Chrome historically doesn't
  // support .local; those users type 192.168.4.1 directly.
  if (MDNS.begin("solesense")) {
    MDNS.addService("http", "tcp", 80);
    Serial.println("[mDNS] solesense.local resolving");
  } else {
    Serial.println("[mDNS] init FAILED (continuing without)");
  }

  http_register_routes(server);
  server.begin();
  Serial.println("[HTTP] server started");

  start_sample_timer();
  Serial.printf("[Timer] %u Hz sampling armed\n", (unsigned)SAMPLE_RATE_HZ);
}

// -- loop() -------------------------------------------------------------------
void loop() {
  state_tick();
  auth_serial_console_tick();   // listen for "factory_reset" from USB serial

  if (gSleepRequested) {
    gSleepRequested = false;
    enter_foot_press_standby();
    // Returns here on wake (light sleep preserves stack + RAM, unlike
    // the old deep_sleep flow). WiFi AP is back up; loop continues.
    return;
  }

  // Auto-standby on false wake: if we just came back from standby and
  // no phone has connected within the grace window, go back to sleep.
  check_wake_grace_window();

  if (gRunActive && gNewSample) {
    gNewSample = false;
    process_sample();
  }

  delay(1);
}

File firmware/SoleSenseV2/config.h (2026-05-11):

// =============================================================================
// SoleSense v0.2 -- config.h
// All compile-time constants live here.
// =============================================================================

#pragma once

#include <Arduino.h>

// -- Identity -----------------------------------------------------------------
constexpr const char* SS_FIRMWARE_VERSION = "v0.2-dev";
constexpr const char* SS_BOARD_NAME       = "XIAO ESP32-C3";

// -- WiFi AP ------------------------------------------------------------------
constexpr const char* SS_AP_SSID = "SoleSense";
constexpr const char* SS_AP_PASS = "solesense";

// -- Pin map (per hardware/electricalpins.pdf) --------------------------------
// XIAO ESP32-C3 Seeed-name -> GPIO mapping for reference:
//   D0..D2 (A0..A2) = GPIO2/3/4    -- shared FSR ADCs
//   D4              = GPIO6        -- I2C SDA
//   D5              = GPIO7        -- I2C SCL
//   D6              = GPIO21       -- IMU INT
//   D7              = GPIO20       -- FSR power set 1
//   D8              = GPIO8        -- FSR power set 2
//   D9              = GPIO9        -- on-board BOOT button (wake)
constexpr uint8_t PIN_SDA       = 6;    // D4  - I2C SDA  -> MPU-6050 SDA
constexpr uint8_t PIN_SCL       = 7;    // D5  - I2C SCL  -> MPU-6050 SCL
constexpr uint8_t PIN_IMU_INT   = 21;   // D6  - MPU-6050 INT (reserved; unused today)
constexpr uint8_t PIN_ADC_A     = 2;    // D0  - shared analog A (FSR 1A / 2A)
constexpr uint8_t PIN_ADC_B     = 3;    // D1  - shared analog B (FSR 1B / 2B)
constexpr uint8_t PIN_ADC_C     = 4;    // D2  - shared analog C (FSR 1C / 2C)
constexpr uint8_t PIN_PWR_SET1  = 20;   // D7  - FSR Set 1 power (1A/1B/1C)
constexpr uint8_t PIN_PWR_SET2  = 8;    // D8  - FSR Set 2 power (2A/2B/2C)
constexpr uint8_t PIN_WAKE      = 9;    // D9  - on-board BOOT button

// -- MPU-6050 -----------------------------------------------------------------
constexpr uint8_t MPU6050_ADDR     = 0x68;
constexpr float   ACCEL_LSB_PER_G  = 16384.0f;
constexpr float   G_TO_MS2         = 9.80665f;
constexpr float   GYRO_LSB_PER_DPS = 131.0f;

// IMU sensor-fusion: accel_z stddev required to consider the IMU "connected"
// (a disconnected MPU leaves gAccel pinned, so stddev sits at exactly 0).
constexpr float IMU_CONNECTED_STDDEV_FLOOR = 0.05f;
// |accel_z - running_mean| above this many m/s^2 is registered as an impact.
constexpr float IMU_IMPACT_DELTA_MS2       = 8.0f;

// -- Sampling -----------------------------------------------------------------
// 500 Hz: chosen to oversample running-impact rising edges (~5-20 ms wide) by
// 5-10x, so FSR-jerk extrapolation has enough resolution for honest loading-
// rate math. Per-sample budget at this rate: ~2 ms; measured ~600 us (matrix
// scan + I^2C IMU + Goertzel + outlier check), leaves ~1.4 ms slack. RAM is
// rate-independent because the Goertzel FFT is incremental (no growing sample
// buffer). Hard ceiling on this MCU/sensor stack is ~1.5 kHz; 500 is the
// comfortable working point.
constexpr uint32_t SAMPLE_RATE_HZ      = 500;
constexpr uint32_t SAMPLE_PERIOD_US    = 1000000UL / SAMPLE_RATE_HZ;
constexpr uint8_t  N_FSR               = 6;
constexpr uint8_t  N_IMU_AXES          = 6;           // ax, ay, az, gx, gy, gz
constexpr uint8_t  N_CHANNELS_TOTAL    = N_FSR + N_IMU_AXES;

// -- FFT (Goertzel bins) ------------------------------------------------------
// See fft.h for the actual frequency table. Sized for ~9KB of state.
constexpr uint8_t  FFT_BINS_PER_CHAN   = 18;
constexpr uint16_t FFT_TOTAL_BINS      = N_CHANNELS_TOTAL * FFT_BINS_PER_CHAN;

// -- Outlier buffer -----------------------------------------------------------
constexpr uint8_t  OUTLIER_CAPACITY    = 100;
constexpr float    OUTLIER_SIGMA_THRESH = 3.0f;       // > N stddev from running mean

// -- Storage (multi-slot ring buffer) -----------------------------------------
constexpr uint8_t  STORAGE_SLOT_COUNT      = 10;
constexpr uint32_t STORAGE_SLOT_SIZE_BYTES = 10240;   // 10 KB per slot, 100 KB total
constexpr const char* STORAGE_FILENAME     = "/run.bin";
constexpr uint32_t STORAGE_FLUSH_MS        = 3000;    // flush every 3 seconds
constexpr uint32_t STORAGE_MAGIC_HEADER    = 0x55EAB001;
constexpr uint32_t STORAGE_MAGIC_TRAILER   = 0xC0DEF00D;

// -- HTTP server --------------------------------------------------------------
constexpr uint16_t HTTP_PORT = 80;

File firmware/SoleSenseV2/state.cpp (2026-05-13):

// =============================================================================
// SoleSense v0.2 -- state.cpp
// =============================================================================

#include "state.h"
#include "config.h"
#include "sensors.h"
#include "fft.h"
#include "outliers.h"
#include "stats.h"
#include "storage.h"

#include <WiFi.h>

volatile RunState gState        = RS_IDLE;
volatile bool gRunActive        = false;
volatile uint32_t gRunElapsedMs = 0;
volatile uint32_t gLastActiveMs = 0;
volatile uint32_t gSampleCount  = 0;
volatile float    gMaxJerkZ     = 0.0f;
volatile bool gNewSample        = false;
volatile bool gStartRequested   = false;
volatile bool gStopRequested    = false;
volatile bool gSleepRequested   = false;
volatile uint32_t gPauseStartMs = 0;
volatile bool gResetSampleTracking = false;

volatile uint32_t gStepCount       = 0;
volatile uint32_t gContactSumMs    = 0;
volatile uint32_t gContactCount    = 0;
volatile float    gMaxHeelJerk     = 0.0f;
volatile uint32_t gLastImuImpactMs = 0;
volatile bool     gImuConnected    = false;
volatile uint32_t gImuImpactCount  = 0;
volatile float    gMaxTotalPressure = 0.0f;

static uint32_t sLastFlushMs = 0;

// Step-detector state (private to this translation unit; reset at /api/start).
static bool     sHeelInContact          = false;
static uint32_t sStepContactStartMs     = 0;
static uint32_t sStepLastImpactMs       = 0;
static float    sStepPeak               = 0.0f;   // peak heel ADC seen during current contact

// 2-state constant-velocity Kalman filter on the heel composite.
// x = [pressure, velocity]^T, F = [[1, dt],[0, 1]], H = [1, 0].
// Q derived from a white-noise-acceleration model (sigma_a ~ 1e5 ADC/s^2);
// R = 25 approximates 5 LSB ADC noise variance.
struct KalmanCV {
  float x0, x1;                 // state: pressure, velocity (ADC counts, counts/s)
  float P00, P01, P10, P11;     // 2x2 covariance
  static constexpr float DT  = 1.0f / (float)SAMPLE_RATE_HZ;
  static constexpr float Q00 = 4.0e-2f;
  static constexpr float Q01 = 4.0e1f;
  static constexpr float Q11 = 4.0e4f;
  static constexpr float R   = 25.0f;

  void reset() {
    x0 = x1 = 0.0f;
    P00 = 1000.0f; P01 = 0.0f; P10 = 0.0f; P11 = 1000.0f;
  }

  void update(float z) {
    // Predict
    x0 = x0 + DT * x1;
    float pp00 = P00 + DT * (P10 + P01) + DT * DT * P11 + Q00;
    float pp01 = P01 + DT * P11 + Q01;
    float pp10 = P10 + DT * P11 + Q01;
    float pp11 = P11 + Q11;
    // Update (innovation y = z - H x, S = H P H^T + R = pp00 + R)
    float S  = pp00 + R;
    float K0 = pp00 / S;
    float K1 = pp10 / S;
    float y  = z - x0;
    x0 += K0 * y;
    x1 += K1 * y;
    // Posterior covariance: (I - K H) P
    P00 = (1.0f - K0) * pp00;
    P01 = (1.0f - K0) * pp01;
    P10 = -K1 * pp00 + pp10;
    P11 = -K1 * pp01 + pp11;
  }
};
static KalmanCV sHeelKalman;

void state_init() {
  gState           = RS_IDLE;
  gRunActive       = false;
  gRunElapsedMs    = 0;
  gLastActiveMs    = 0;
  gSampleCount     = 0;
  gNewSample       = false;
  gStartRequested  = false;
  gStopRequested   = false;
  gSleepRequested  = false;
  gPauseStartMs    = 0;
  sLastFlushMs     = 0;
}

static void enter_recording() {
  // Reset all per-run state.
  gRunElapsedMs = 0;
  gSampleCount  = 0;
  gMaxJerkZ     = 0.0f;
  gLastActiveMs = millis();
  gPauseStartMs = 0;
  gStepCount        = 0;
  gContactSumMs     = 0;
  gContactCount     = 0;
  gMaxHeelJerk      = 0.0f;
  gLastImuImpactMs  = 0;
  gImuConnected     = false;
  gImuImpactCount   = 0;
  gMaxTotalPressure = 0.0f;
  sHeelInContact      = false;
  sStepContactStartMs = 0;
  sStepLastImpactMs   = 0;
  sStepPeak           = 0.0f;
  sHeelKalman.reset();
  fft_reset();
  outliers_reset();
  stats_reset();
  storage_begin_run();
  gState     = RS_RECORDING;
  gRunActive = WiFi.softAPgetStationNum() > 0;
  gResetSampleTracking = true;   // first sample after start gets a clean derivative-history
  Serial.println("[Run] started");
}

static void exit_recording() {
  gRunActive = false;
  storage_end_run(gRunElapsedMs, gSampleCount);
  gState = RS_IDLE;
  Serial.printf("[Run] stopped after %lu ms / %lu samples\n",
                (unsigned long)gRunElapsedMs, (unsigned long)gSampleCount);
}

void state_tick() {
  // 1. Service request flags (set by HTTP handlers on the AsyncWebServer task).
  if (gStartRequested) {
    gStartRequested = false;
    if (gState == RS_IDLE) enter_recording();
  }
  if (gStopRequested) {
    gStopRequested = false;
    if (gState == RS_RECORDING) exit_recording();
  }
  // gSleepRequested is consumed by SoleSenseV2.ino directly (calls deep_sleep()).

  // 2. Pause-on-disconnect (only relevant while recording).
  if (gState != RS_RECORDING) return;

  uint8_t clients = WiFi.softAPgetStationNum();
  uint32_t now = millis();

  if (gRunActive && clients == 0) {
    // Just lost all clients -- pause.
    gRunElapsedMs += (now - gLastActiveMs);   // commit the in-progress active interval
    gRunActive    = false;
    gPauseStartMs = now;
    Serial.println("[Run] paused (no clients)");
  } else if (!gRunActive && clients > 0) {
    // Just regained a client -- resume. Reset the jerk-prev tracking so
    // the next sample doesn't compute a giant spurious jerk over the
    // pause-duration gap and falsely fire the high_loading flag.
    gLastActiveMs = now;
    gRunActive    = true;
    gResetSampleTracking = true;
    Serial.printf("[Run] resumed after %lu ms paused\n",
                  (unsigned long)(now - gPauseStartMs));
    gPauseStartMs = 0;
  } else if (gRunActive) {
    // Still active -- advance the running-elapsed cheaply (small per-tick adds keep
    // /api/run-state responsive even between flushes).
    gRunElapsedMs += (now - gLastActiveMs);
    gLastActiveMs = now;
  }

  // 3. Periodic flash flush (only while active).
  if (gRunActive && (now - sLastFlushMs) >= STORAGE_FLUSH_MS) {
    sLastFlushMs = now;
    storage_save_snapshot(gRunElapsedMs, gSampleCount);
  }
}

const char* state_name() {
  return gState == RS_IDLE ? "idle" : "recording";
}
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

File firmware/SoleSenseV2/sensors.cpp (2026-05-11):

// =============================================================================
// SoleSense v0.2 -- sensors.cpp
// =============================================================================

#include "sensors.h"

#include <Wire.h>

int16_t gFsr[N_FSR]      = {0,0,0,0,0,0};
int16_t gFsrEma[N_FSR]   = {0,0,0,0,0,0};
float   gAccel[3]        = {0,0,0};
float   gGyro[3]         = {0,0,0};
int     gFsrZero[N_FSR]  = {0,0,0,0,0,0};
float   gImuOffset[6]    = {0,0,0,0,0,0};

// 4-sample oversampling kills high-frequency noise (60 Hz hum, switching
// transients, breadboard capacitive coupling). The first read after a
// multiplexer switch is often slightly dirty; averaging 4 reads dilutes
// the warm-up sample without adding a separate discard step. ~12 us per
// channel x 3 channels = ~36 us extra per set, well under the 1.4 ms
// per-sample slack we measured.
static inline int read_adc_oversampled(uint8_t pin) {
  int sum = 0;
  for (uint8_t i = 0; i < 4; i++) sum += analogRead(pin);
  return sum >> 2;
}

// Drive the inactive set's power pin LOW (not floating) so any ghost
// current path from a pressed FSR shorts to GND instead of propagating
// across to the other ADC pins. 200 us settling per set fits the 2 ms
// per-sample budget at 500 Hz with margin and gives the analog domain
// extra headroom on noisy breadboard prototypes.
static void read_set_a() {
  pinMode(PIN_PWR_SET2, OUTPUT);
  digitalWrite(PIN_PWR_SET2, LOW);
  pinMode(PIN_PWR_SET1, OUTPUT);
  digitalWrite(PIN_PWR_SET1, HIGH);
  delayMicroseconds(200);
  gFsr[0] = read_adc_oversampled(PIN_ADC_A) - gFsrZero[0];   // Heel medial
  gFsr[1] = read_adc_oversampled(PIN_ADC_B) - gFsrZero[1];   // Heel lateral
  gFsr[2] = read_adc_oversampled(PIN_ADC_C) - gFsrZero[2];   // Midfoot medial
}

static void read_set_b() {
  pinMode(PIN_PWR_SET1, OUTPUT);
  digitalWrite(PIN_PWR_SET1, LOW);
  pinMode(PIN_PWR_SET2, OUTPUT);
  digitalWrite(PIN_PWR_SET2, HIGH);
  delayMicroseconds(200);
  gFsr[3] = read_adc_oversampled(PIN_ADC_A) - gFsrZero[3];   // Midfoot lateral
  gFsr[4] = read_adc_oversampled(PIN_ADC_B) - gFsrZero[4];   // Forefoot medial
  gFsr[5] = read_adc_oversampled(PIN_ADC_C) - gFsrZero[5];   // Forefoot lateral
}

// Drive both sets LOW between active reads so any leakage path is grounded
// rather than floating. Despite the name's history, this is active-LOW, not
// true high-Z; the LOW state is what kills ghost crosstalk through the
// unpowered FSRs.
static void park_sets_grounded() {
  pinMode(PIN_PWR_SET1, OUTPUT);
  pinMode(PIN_PWR_SET2, OUTPUT);
  digitalWrite(PIN_PWR_SET1, LOW);
  digitalWrite(PIN_PWR_SET2, LOW);
}

static void read_imu() {
  Wire.beginTransmission(MPU6050_ADDR);
  Wire.write(0x3B);                               // ACCEL_XOUT_H
  Wire.endTransmission(false);
  Wire.requestFrom((uint8_t)MPU6050_ADDR, (uint8_t)14);

  int16_t ax = (Wire.read() << 8) | Wire.read();
  int16_t ay = (Wire.read() << 8) | Wire.read();
  int16_t az = (Wire.read() << 8) | Wire.read();
  Wire.read(); Wire.read();                       // discard temp
  int16_t gx = (Wire.read() << 8) | Wire.read();
  int16_t gy = (Wire.read() << 8) | Wire.read();
  int16_t gz = (Wire.read() << 8) | Wire.read();

  gAccel[0] = (ax / ACCEL_LSB_PER_G) * G_TO_MS2 - gImuOffset[0];
  gAccel[1] = (ay / ACCEL_LSB_PER_G) * G_TO_MS2 - gImuOffset[1];
  gAccel[2] = (az / ACCEL_LSB_PER_G) * G_TO_MS2 - gImuOffset[2];
  gGyro[0]  = gx / GYRO_LSB_PER_DPS - gImuOffset[3];
  gGyro[1]  = gy / GYRO_LSB_PER_DPS - gImuOffset[4];
  gGyro[2]  = gz / GYRO_LSB_PER_DPS - gImuOffset[5];
}

void sensors_init() {
  pinMode(PIN_PWR_SET1, INPUT);
  pinMode(PIN_PWR_SET2, INPUT);
  pinMode(PIN_ADC_A,    INPUT);
  pinMode(PIN_ADC_B,    INPUT);
  pinMode(PIN_ADC_C,    INPUT);
  analogReadResolution(12);

  Wire.begin(PIN_SDA, PIN_SCL);
  Wire.setClock(400000);

  // MPU-6050 wake + default ranges (+/-2g, +/-250 deg/s).
  Wire.beginTransmission(MPU6050_ADDR);
  Wire.write(0x6B); Wire.write(0x00);
  Wire.endTransmission();
  delay(10);
  Wire.beginTransmission(MPU6050_ADDR);
  Wire.write(0x1B); Wire.write(0x00);
  Wire.endTransmission();
  Wire.beginTransmission(MPU6050_ADDR);
  Wire.write(0x1C); Wire.write(0x00);
  Wire.endTransmission();
  Serial.println("[Sensors] FSR sets + MPU-6050 initialised");
}

void sensors_read_all() {
  read_set_a();
  read_set_b();
  park_sets_grounded();
  read_imu();

  // EMA on the FSR readings for the live UI. gFsr stays raw so the step
  // detector / Kalman / FFT / stats all see unfiltered samples; gFsrEma is
  // strictly for the visual fill of the foot-diagram circles, which were
  // noticeably jittery on the raw signal.
  for (uint8_t i = 0; i < N_FSR; i++) {
    float prev = (float)gFsrEma[i];
    float next = FSR_EMA_ALPHA * (float)gFsr[i] + (1.0f - FSR_EMA_ALPHA) * prev;
    gFsrEma[i] = (int16_t)next;
  }
}

void sensors_calibrate_fsr() {
  for (int i = 0; i < N_FSR; i++) gFsrZero[i] = 0;
  long acc[N_FSR] = {0,0,0,0,0,0};
  for (int s = 0; s < 32; s++) {
    sensors_read_all();
    for (int i = 0; i < N_FSR; i++) acc[i] += gFsr[i];
    delay(1);
  }
  for (int i = 0; i < N_FSR; i++) gFsrZero[i] = (int)(acc[i] / 32);
  Serial.printf("[Cal] FSR zeros: %d %d %d %d %d %d\n",
    gFsrZero[0],gFsrZero[1],gFsrZero[2],gFsrZero[3],gFsrZero[4],gFsrZero[5]);
}

void sensors_calibrate_imu() {
  for (int i = 0; i < 6; i++) gImuOffset[i] = 0;
  double acc[6] = {0,0,0,0,0,0};
  const int N = 64;
  for (int s = 0; s < N; s++) {
    sensors_read_all();
    acc[0] += gAccel[0]; acc[1] += gAccel[1]; acc[2] += gAccel[2];
    acc[3] += gGyro[0];  acc[4] += gGyro[1];  acc[5] += gGyro[2];
    delay(2);
  }
  gImuOffset[0] = (float)(acc[0] / N);
  gImuOffset[1] = (float)(acc[1] / N);
  gImuOffset[2] = (float)(acc[2] / N) - G_TO_MS2;
  gImuOffset[3] = (float)(acc[3] / N);
  gImuOffset[4] = (float)(acc[4] / N);
  gImuOffset[5] = (float)(acc[5] / N);
  Serial.printf("[Cal] IMU offsets accel %.2f %.2f %.2f gyro %.2f %.2f %.2f\n",
    gImuOffset[0],gImuOffset[1],gImuOffset[2],
    gImuOffset[3],gImuOffset[4],gImuOffset[5]);
}

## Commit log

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2026-04-30 Add files via upload
    CAD of FSR Cutout for Sole
    0.125cm of tolerance
    [FSR Cutout.SLDPRT]
2026-05-01 Add files via upload
    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
    [FSR Cutout.SLDPRT]
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2026-05-04 Add v0.1 firmware implementation plan
    13 task plan covering: project skeleton, WiFi AP, LittleFS + test
    panel, all 10 HTTP endpoints, NVS-backed thresholds + calibration,
    50 Hz sampling with ring-buffered CSV writes, deep sleep on GPIO9,
    end-to-end smoke test, and frontend swap-in.
    Each task: Arduino IDE compile -> flash -> curl/serial verify -> commit.
    Plan front-loads demo-able milestones so any stop point gives a
    slide-able artifact.
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2026-05-04 Updated the code to not show live reports. Only the timer is showed, and the reports show dummy random data. We will fix this when real sensors are plugged in and read.
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2026-05-06 V0.2 scaffold — modular sketch + plan
    New: firmware/SoleSenseV2/. Compiles and boots on the XIAO ESP32-C3.
    Brings up the SoleSense WiFi AP, registers all v0.2 HTTP routes, runs
    the 50 Hz sample loop with pause-on-disconnect, and routes each sample
    through online running stats -> outlier detector -> FFT.
    Module status:
    ✅ config.h all constants
    ✅ state.h/.cpp run state machine + pause-on-disconnect
    ✅ sensors.h/.cpp FSR matrix-scan + MPU-6050 (lifted from v0.1)
    ✅ outliers.h/.cpp fixed-capacity min-heap on |sigma|
    ✅ SoleSenseV2.ino top-level: setup, loop, ISR, deep sleep,
    Welford online stats per channel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
    [SoleSenseV2.ino, config.h, fft.cpp]
2026-05-06 Task 4 — implement and validate Goertzel FFT
    Real, scaled, DC-removed Goertzel implementation. The previous stub had
    the recurrence in the right shape but the magnitude scaling was wrong
    (divided by sample count instead of using the proper 2/N single-sided
    amplitude factor) and there was no DC removal, so non-zero-mean signals
    would smear into low bins.
    What's there now:
    - Windowed Goertzel with FFT_WIN_SIZE=256 samples (~5 s at 50 Hz). After
    each window, magnitudes are computed and cached in sMag[c][b]; state
    is reset for the next window.
    - Per-bin precomputed cos(omega), sin(omega), 2*cos(omega).
    - DC removal: running_mean parameter (Welford-style) is subtracted from
    each sample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
    [SoleSenseV2.ino, fft.cpp]
2026-05-07 Task 5 — multi-slot ring buffer storage
    Crash-safe persistence for the v0.2 run state. Every STORAGE_FLUSH_MS
    (=3 s) the firmware serialises {FFT magnitudes + outlier buffer +
    reserved meta} into a CRC32-protected slot file. Slots round-robin
    across STORAGE_SLOT_COUNT (=10) files so a power-cut mid-write only
    costs the in-progress slot — the previous nine remain valid.
    Implementation choices:
    - Per-slot files (/run_slot_0.bin .. /run_slot_9.bin) instead of one
    big file with seek/r+ writes. Each save is open("w")+write+close;
    LittleFS handles atomicity for individual file writes. Simpler,
    more robust, and works without depending on Arduino LittleFS's
    seek+overwrite behaviour.
    -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
    [storage.cpp]
2026-05-07 Task 6 — run-report analysis from FFT + outliers + stats
    /api/run-report now returns real metrics computed on-MCU. The placeholder
    JSON is replaced with cadence, GCT, loading-rate, pronation, L/R balance,
    pressure distribution, and the 7 injury flags — output shape matches the
    v0.1 dao UI's existing render() function so the report screen renders
    directly off this response with no JS changes.
    What each metric reads:
    cadence peak FFT bin in heel channel (FSR 0) within 1–4 Hz, * 60
    zoneAvg.* per-channel running mean (heel, midfoot, ball, toe)
    lPct/rPct medial vs lateral split of FSR running means
    loadingRate largest FSR-channel outlier sigma * 10 (proxy)
    pronat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
    [SoleSenseV2.ino, state.cpp]
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2026-05-08 Swap to ESP-IDF 4.x deep-sleep wake API for compatibility
    Both v0.1 and v0.2 used esp_deep_sleep_enable_gpio_wakeup() with
    ESP_GPIO_WAKEUP_GPIO_LOW. That pair is only declared in newer Arduino-
    ESP32 cores (3.x). On older cores or some installations the compile
    fails with 'ESP_GPIO_WAKEUP_GPIO_LOW was not declared in this scope'.
    Switching to the older but universally-supported API:
    gpio_wakeup_enable((gpio_num_t)PIN_WAKE, GPIO_INTR_LOW_LEVEL);
    esp_sleep_enable_gpio_wakeup();
    esp_deep_sleep_start();
    Same behaviour: wake on GPIO9 going LOW. Compiles on Arduino-ESP32
    core 2.x and 3.x.
    v0.1 had a working flashed binary (compiled before the user upgraded
    their core), so they hadn'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
    [SoleSenseV2.ino]
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2026-05-08 IMU-jerk loading rate (BW/s) + better foot SVG
    Two requests from the team review.
    1. FSR 402 caps at ~10 kg, far below running impact (1.5–3× body weight,
    so 100–200 kg ground-reaction force at heel strike). The FSR can't
    measure peak force; trying to derive loading rate from FSR sigma was
    measuring sensor saturation, not impact.
    Fix: track vertical jerk (d(accel_z)/dt) from the IMU, which is
    independent of any force-sensor saturation. Dividing peak |jerk_z|
    by g (9.81 m/s²) gives loading rate in body-weights-per-second, the
    standard biomechanics unit (Milner 2006). Healthy runners read 30–80
    BW/s; > 80 is associated with stress-fracture risk.
    Implementat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
    [SoleSenseV2.ino, state.cpp]
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2026-05-08 Bump sample rate 50 → 500 Hz, redistribute FFT bins
    v0.2's storage architecture stores FFT magnitudes + outliers, not raw
    samples, so RAM cost is independent of sample rate (Goertzel is
    incremental). The old 50 Hz was a v0.1-era CSV-streaming constraint that
    no longer applies.
    500 Hz is chosen to oversample running-impact rising edges (5–20 ms wide)
    by 5–10×, giving FSR-jerk extrapolation enough time-domain resolution to
    recover impact magnitude through the 10 kg FSR saturation. Per-sample
    budget is ~2 ms; measured per-sample work is ~600 µs, so plenty of slack.
    FFT changes:
    - FFT_WIN_SIZE 256 → 1024 (so 0.5 Hz cadence stays resolvable; window
    is now 2.05 s @ 500 Hz vs 5.12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
    [config.h, fft.cpp]
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2026-05-09 Time-domain step counter + ground-contact-time
    Replaces the FFT-derived cadence (which needed 2+ s of rhythmic input
    before any step would register) with a Schmitt-trigger step detector
    on the heel channel:
    - Rising edge through max(200 ADC, 4σ above mean) = heel-strike,
    increments gStepCount
    - Falling edge through 80 ADC = toe-off; valid contact intervals
    [50, 800] ms are added to the rolling GCT average
    - 150 ms refractory period prevents bounce double-counts
    This kills the "I press the FSR and steps stays 0" feedback gap for
    single presses, and gives an honest contactMs value for free.
    Cadence is now (steps × 60 / runtime), gated to require ≥2 s of run
    time so very-sho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
    [SoleSenseV2.ino, state.cpp]
2026-05-09 Step detector — drop σ-based threshold (self-poisoning)
    The 4σ component of the rise threshold was *poisoned* by the press
    samples it was meant to filter. Welford σ on the heel channel includes
    all samples (press AND rest), so after one heel-strike σ jumps to
    ~325 ADC counts. 4σ ≈ 1300 then becomes the rise threshold, which no
    finger press ever clears — so press #2, #3, #4 all silently fail.
    Symptom: "I press the sensor multiple times but step count stops at 1".
    Fix: use absolute ADC thresholds (400 rise / 200 fall) instead of
    mean-relative. Justification: the FSR rests at 0–150 and a real press
    reaches 500–3000+, so the 400/200 hysteresis cleanly separates them
    without any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
    [state.cpp]
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2026-05-09 FSR-jerk loading rate + clamp negative zones
    Two fixes:
    1. Loading rate (was 0/"—") now reports a real BW/s value via FSR-jerk
    extrapolation:
    - Per-sample d(heelComposite)/dt is tracked in process_sample(),
    gMaxHeelJerk holds the run's peak in ADC counts/s.
    - run-report converts using FSR saturation (10 kg @ ADC=4095) and an
    assumed 70 kg body weight: BW/s ≈ counts/s × 3.488e-5.
    - Healthy band 30–80 BW/s; >80 fires the high_loading injury flag.
    - Body weight will become user-configurable via /api/settings later.
    2. Zone means clamped to ≥0 to fix "-0%" display: when a sensor is
    unconnected, a stale calibration offset can pull Welford means
    slightly n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
    [SoleSenseV2.ino, sensors.cpp, state.cpp]
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2026-05-09 Step-counter only on valid release; foot diagram uses CAD render
    Step detector:
    - gStepCount no longer increments on every rising edge. FSR signals ring
    during a single physical press (rises, drops below peak/2, rises again
    at the refractory boundary), so the previous logic counted 98 "steps"
    from 6 actual finger presses.
    - New behavior: rising edge = TENTATIVE (start tracking). Step is only
    credited at toe-off if the contact lasted [50, 800] ms — i.e., long
    enough to be a real press but not so long it's a lean. Bouncy
    oscillations within a press log as [Step] discard and don't count.
    - Pronation is clamped to 0 if |gyro_x mean| < 0.5 °/s so the UI shows
    "0.0°" instead of "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
    [state.cpp]
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2026-05-09 Step detector OR-gates all 6 FSR zones
    Was: step counted only on heel-strike (max(ch0, ch1) > 400 ADC) — broke
    for forefoot strikers and for finger-pressing the midfoot/forefoot pads
    during demos.
    Now: step counted on a strike from ANY of the 6 FSR zones. The detector
    takes max(ch0..ch5) and the same Schmitt logic applies. Refractory bumped
    from 150 → 250 ms so the natural heel→midfoot→forefoot pressure
    progression within a single stride doesn't fire multiple strikes.
    The FSR-jerk loading-rate tracker also now uses the any-zone max so peak
    rate-of-rise is captured wherever on the foot the impact lands.
    Note: this is intentionally subject to change once the IMU is wired and
    we can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
    [SoleSenseV2.ino, state.cpp]
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2026-05-09 Profile/auth system + sensor-fusion polish + edge-case fixes
    Big multi-area drop. Spec:
    docs/superpowers/specs/2026-05-09-profile-system.md
    == Profile / auth system ==
    - New auth.h/cpp module: NVS-backed user accounts, SHA-256(pin || salt),
    one active session at a time (RAM only), 30-min idle timeout, owner-
    claim model (first registration unrestricted, subsequent require owner
    token), 3-failures→30-s lockout per username.
    - New endpoints: /api/auth/{state, register, login, logout, profile}.
    - Middleware require_auth() applied to all state-changing routes:
    /api/start, /api/stop, /api/sleep, /api/calibrate/{zero,imu}.
    - Frontend: new login/claim screen as the first-shown view; auth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
    [SoleSenseV2.ino, auth.cpp]
2026-05-09 NVS key length + prettier auth screen
    NVS keys are limited to 15 chars. The previous "u/<username>/pinhash"
    scheme overflows once the username is more than ~5 characters, which is
    why the user got an "nvs error" claiming the device. Refactored to:
    - 2-char prefix per field (s_ for salt, h_ for pinhash, w_ for body)
    - Username constrained to 3–13 chars, [a-zA-Z0-9_]
    - Existence check now uses isKey() instead of getString-on-bytes-key
    Also added a Serial.printf on NVS-write failure so future regressions
    are easier to root-cause.
    UI: auth screen now uses the home-screen visual language — eyebrow +
    hero headline + branded form fields with focused-state ring + the
    gradient pill button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
    [auth.cpp]
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2026-05-09 USB-serial 'factory_reset' command for auth NVS
    The README said factory reset was via "USB-serial command" but the
    command was never wired. Today's bug — user got "invalid credentials"
    on a freshly-claimed account because of stale data left by the
    NVS-key-too-long bug — meant we had no recovery path short of full
    re-flash. Now adding a serial console that reads stdin and acts on:
    factory_reset Preferences.clear() the auth namespace, drop the
    active session, return to claim mode.
    Anything else logs as "unknown command". The console runs from loop()
    each tick (auth_serial_console_tick), so it's responsive even while a
    recording is in progress.
    Verified on hardwar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
    [SoleSenseV2.ino, auth.cpp]
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2026-05-09 Multi-user support — Add user button + auto-login fix
    The owner-claim model has always allowed multiple accounts on a single
    device, but the frontend never exposed a way to create them and the
    backend had a bug where adding a user mid-session would yank the owner
    into the new user's session.
    Backend (auth.cpp + http_routes.cpp):
    - auth_register() now captures auth_in_claim_mode() BEFORE writing the
    new user, so the auto-login decision is based on whether THIS call is
    the very first registration. Subsequent calls (from a logged-in
    owner) skip auto-login entirely; the owner stays signed in.
    - handle_auth_register() returns a token only for the claim-mode case;
    for owner-adds-seconda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
    [auth.cpp]
2026-05-09 Self-signup on the auth screen + specific error copy
    - Auth screen now has a Sign-in / Create-account toggle. Tap "Create
    one" to switch to signup; body-weight field appears, headline copy
    changes, button label changes. When no owner exists yet, signup is
    forced and the toggle is hidden ("Claim your insole.").
    - Anyone connected to the SoleSense WiFi can now self-signup; the
    /api/auth/register endpoint dropped its owner-only check. The shared
    WiFi password (`solesense`) already gates network access — layering
    an owner-token check on top blocked legitimate household members
    from making themselves an account.
    - New users are auto-logged-in atomically.
    - Granular error codes for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
    [auth.cpp]
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2026-05-09 Kill matrix-scan crosstalk + show cadence on short runs
    == Sensor crosstalk ==
    read_set_a / read_set_b were leaving the inactive power-set pin
    floating (pinMode INPUT). Pressing an FSR raises the voltage at its
    ADC pin; with the inactive set high-Z, that voltage leaked back
    through any FSR in the floating set, lifted the floating power
    node, and ghosted onto the other two ADC pins — classic matrix-
    scan ghosting, exactly what the user saw when pressing the heel
    made midfoot/forefoot readings rise.
    Fix: drive the inactive set's power pin LOW (active ground) so the
    ghost current path bleeds straight to GND instead of floating up.
    park_sets_high_z() now also actively grounds both sets when n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
    [sensors.cpp]
2026-05-09 Hostname (solesense.local) + captive portal + live conn dot
    == Friendly URL ==
    - mDNS responder: http://solesense.local/ resolves on iOS/macOS without
    needing to type the IP. Bonjour service advertised on http/tcp:80.
    - DNS captive portal: a DNS server runs on UDP:53 and answers EVERY
    query with the AP's IP. Two consequences:
    1. Joining the SoleSense WiFi triggers iOS/Android's auto-popup
    captive-portal handoff to the SoleSense UI — no URL typed.
    2. Even on Android (no .local support), typing literally any URL
    lands on the device, so the user has nothing to memorise.
    gDns.processNextRequest() runs each loop() tick.
    == Live connection dot ==
    - The status dot at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
    [SoleSenseV2.ino]
2026-05-11 Replace Schmitt-trigger step detector with 2-state Kalman
    The previous detector used absolute ADC thresholds + a peak-relative fall
    threshold. That worked but needed bookkeeping (sStepPeak, refractory
    band-aids for FSR ringing). Reworked the detector around a 2-state
    constant-velocity Kalman filter whose state is the heel composite's
    smoothed pressure + velocity.
    Model:
    x[k+1] = F x[k] + w, F = [[1, dt],[0, 1]], w ~ N(0, Q)
    z[k] = H x[k] + v, H = [1, 0], v ~ N(0, R)
    Q is built from a white-noise-acceleration assumption with
    σ_a ≈ 1e5 ADC counts/s² (large enough to track impact transients
    of 5-20 ms width without smoothing them away).
    R = 25 ≈ 5 LSB A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
    [state.cpp]
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2026-05-11 Drop captive-portal auto-popup; keep only mDNS
    The captive-portal auto-handoff was annoying (sandbox WebView, no
    persistent cookies, weird popups). Reverting to "user opens browser
    themselves" — same as before the captive portal landed.
    Removed:
    - DNSServer that answered every query with 192.168.4.1
    - HTTP 302 redirects for OS captive-portal probe URLs
    (/hotspot-detect.html, /generate_204, /ncsi.txt, etc.)
    - "Open in browser ↗" escape-hatch link in the home nav + its CSS
    Kept (pure benefit, no popup behaviour):
    - mDNS: http://solesense.local/ still resolves on iOS/macOS
    Behaviour now identical to the pre-captive-portal state:
    • iOS/Android joining the SoleSense WiFi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
    [SoleSenseV2.ino]
2026-05-11 Atomic registration + spam caps + state surface
    Hardening profile storage and signup against abuse. Four changes:
    1. ATOMIC REGISTRATION — auth_register() now writes salt, then hash,
    then body_kg, rolling back any earlier writes on any partial
    failure. Previously a write that succeeded for salt but failed for
    hash left the username permanently locked: isKey(salt) returned
    true (so re-registration said "taken") but login couldn't succeed
    either ("no hash on file"). Now a failed write removes the slot
    cleanly so the user can retry.
    2. TOTAL-ACCOUNT CAP — new MAX_USERS = 20. A new NVS uint16 key "uc"
    tracks the count; auth_register checks it BEFORE any state mutation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
    [auth.cpp]
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2026-05-11 ASCII-only across repo + EMA filter + LICENSE + .gitignore polish
    Three changes in one pass:
    == 1. EMA low-pass filter on FSR signal path ==
    The Kalman filter on the heel composite (state.cpp) is already a
    mathematical low-pass filter, but it's not an EMA and it's only
    applied to the step-detector input. Added a separate EMA on the
    six raw FSR readings for the live-display path:
    - gFsrEma[N_FSR] in sensors.h / sensors.cpp, alpha = 0.15
    -> tau ~= 12 ms at 500 Hz (smooths ADC noise without lagging
    real presses visibly).
    - Updated per call to sensors_read_all() right after the raw read.
    - /api/sensor now returns both fsr[] (raw) AND fsrEma[] (smoothed).
    - Frontend animateBars(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
    [SoleSenseV2.ino, auth.cpp, config.h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]
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2026-05-11 Adopt electricalpins.pdf pin assignments
    Per hardware/electricalpins.pdf (now committed to the repo), the FSR
    power pins move and the IMU gets a reserved INT line:
    FSR Set 1 power : D3 / GPIO5 -> D7 / GPIO20
    FSR Set 2 power : D10 / GPIO10 -> D8 / GPIO8
    IMU INT : (unused) -> D6 / GPIO21 (reserved, not yet used)
    The ADC pins (D0/D1/D2 = GPIO2/3/4), I2C (D4/D5 = GPIO6/7), and the
    wake button (D9 = GPIO9, on-board BOOT) are unchanged.
    PIN_IMU_INT is defined for future low-power wake-on-motion use; the
    firmware doesn't read or interrupt on it today.
    Updates:
    firmware/SoleSenseV2/config.h -- new constants + Seeed/GPIO map
    comment block.
    README.md -- Pin Map s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
    [config.h]
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2026-05-11 Redesign Run Report + multi-pass simplify + doc corrections
    Frontend (software/frontend/solesense-v2/index.html + LittleFS copy):
    - Replace the long scrolling metric grid with an industry-style report:
    hero card (verdict icon + headline + 3-KPI strip), anatomical foot
    pressure heatmap (single-hue HSL gradient on the same insole render
    used by the recording screen), and a collapsible "All technical
    metrics" section with plain-English subtitles + colour-coded pills.
    - Apple-style polish: sticky blurred header, uppercase tracked section
    labels, generous whitespace, softer cards, refined typography.
    - Verdict is data-driven from r.flags + FLAG_DEFS severity; heatmap
    apportions zone a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
    [SoleSenseV2.ino, config.h, sensors.cpp]
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2026-05-11 Final polish: Edit Profile, real /api/data/clear, specific error toasts
    Firmware (firmware/SoleSenseV2/):
    - New `POST /api/auth/profile` endpoint accepts URL-encoded body_kg and/or
    height_cm and updates the signed-in user's NVS profile. Atomic write
    semantics (NVS first, then gSession) so a failed flash write doesn't
    leave the in-RAM session out of sync.
    - New `POST /api/data/clear` endpoint, session-protected. Calls a real
    storage_clear() that removes every /run_slot_N.bin from LittleFS and
    resets the ring pointer. Refuses with 409 while a run is recording.
    - auth_update_profile() helper with granular validation (body_kg 25-250,
    height_cm 100-250) and NaN-as-skip semantics so ca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
    [auth.cpp, storage.cpp]
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2026-05-11 Pre-presentation audit pass: fix stale doc claims, comment lies, .vscode removal
    Caught by three parallel review agents and a manual cross-check:
    HIGH severity:
    - README + research.md claimed a 'long ground contact time' injury flag.
    The firmware computes contactMs but doesn't threshold it -- there is no
    such flag. Updated the injury-flag list to remove it; research.md now
    has the actual flag set (heel_strike, high_loading split out as a
    separate row, low_cadence, overpronation, supination, medial_lateral_asym)
    and an explicit note that GCT is reported as a metric, not flagged.
    - README API table said MAX_USERS=20; the recent bump is 50.
    - firmware/SoleSenseV2/README.md line 166 s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
    [SoleSenseV2.ino]
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2026-05-11 4-sample oversampling + bump settling 150 → 200 µs to suppress FSR crosstalk
    Three small ADC-quality improvements bundled. None changes the behaviour
    the SPA sees -- only the raw signal quality going into the FFT, outlier
    detector, and step detector.
    1. Each FSR analogRead is now a 4-sample average via the new inline
    helper read_adc_oversampled(). The ESP32-C3 ADC samples in ~10 µs,
    so this costs ~36 µs extra per set (~72 µs total per 2 ms sample
    tick) -- well within the measured 1.4 ms slack. Cancels most of the
    high-frequency noise: 60 Hz mains hum, capacitive coupling between
    breadboard rails, switching transients from the set power lines
    toggling.
    2. Inter-set s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
    [sensors.cpp]
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2026-05-13 firmware: reset jerk-prev state on pause/resume + safer deep sleep
    Two demo-critical fixes:
    1. process_sample()'s derivative trackers (sJerkHasPrev, sAnyHasPrev)
    weren't being cleared when the run paused (Wi-Fi drop) and resumed.
    The next sample after resume computed jerk over the gap of milliseconds
    instead of one 2ms tick, producing a spurious huge peak that falsely
    fired the high_loading injury flag. Promoted the FSR-jerk statics to
    file scope alongside the existing IMU-jerk statics and added a
    gResetSampleTracking flag that state.cpp sets on resume (and at run
    start) so the next process_sample clears its prev-history.
    2. enter_deep_sleep() was calling WiFi.softAPdi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
    [SoleSenseV2.ino, state.cpp]
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2026-05-17 firmware: replace deep-sleep with foot-press wake standby
    Old enter_deep_sleep() armed GPIO9 (the on-board BOOT button) as the
    only wake source. The current housing seals over that button, so
    tapping Power Off would brick the device until someone pried the
    case open. The ESP32-C3 only exposes GPIO0-5 as RTC-wake-capable pins,
    all of which are tied up (3x shared ADCs + 2x I2C), and the MPU-6050
    INT line sits on GPIO21 which is not RTC-capable -- so a direct
    GPIO-driven motion wake from deep sleep isn't an option on this
    chip with this pinout either.
    New enter_foot_press_standby() uses light sleep + a 1.5 s RTC timer:
    on each timer wake we briefly power one FSR set, take three ADC
    reads, and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
    [SoleSenseV2.ino]
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
